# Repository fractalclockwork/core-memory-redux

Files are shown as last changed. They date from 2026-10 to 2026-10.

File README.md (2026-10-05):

# core-memory-redux

Ground-up reimplementation of a magnetic core memory array driver and its simulation-in-the-loop (SIL) digital twin.

**Agents:** start at [AGENTS.md](AGENTS.md), then [docs/AUTHORITY.md](docs/AUTHORITY.md) (SSOT map). This README is the human front door; architecture bullets below are a snapshot and defer to owner docs.

## Why this repo exists

This is a rewrite of [`fractalclockwork/core-memory`](https://github.com/fractalclockwork/core-memory), rebuilt as a model project for **simulation-in-the-loop agentic engineering**. The goal is not only a working circuit, but a repeatable process: requirements, tools, generators, fidelity-gated simulation, and documentation that stay aligned as the design evolves.

**Done** means all three deliverables:

1. The engineering process (phased SIL loop, coverage gates, agent-friendly workflow)
2. The circuit (driver for the existing 64×64 ferrite plane)
3. Documentation of the circuit, simulation ladder, and design decisions

## Status

**Docs + L0–L3 sim/SIL + L4 fabric KiCad + multi-board PCB (Phase 5+).** Design contracts live under [`docs/`](docs/). Gates `GATE-L0-PHYSICS` … `GATE-L4-FABRIC` → [coverage_matrix.md](docs/coverage_matrix.md). Generators: [`generators/`](generators/) → [`kicad/`](kicad/) (KiCad **10.0.6**), including `pcb_ccs_sense` + `pcb_axis_octal` ([board_icd.md](docs/board_icd.md)). No firmware / bench fab yet. Claims outside the coverage matrix are *normative target* / `baseline`, not as-built hardware.

**SSOT:** layered authority — one owner per fact category ([docs/AUTHORITY.md](docs/AUTHORITY.md)). Normative definition: [docs/system_design_spec.md](docs/system_design_spec.md) §1. Weave/fabric geometry SSOT: [`generators/mce_array.py`](generators/mce_array.py).

## Record

[writeup/essay.md](writeup/essay.md) is a narrative snapshot of the method, the L0–L3 runs, and the L4 fabric and boards, written as ordinary prose. It is not part of the SSOT. If it disagrees with an owner doc or the coverage matrix, those win.

## Target architecture (snapshot)

Non-authoritative summary — edit owners, not this list:

- **Plane / fold / timing:** [docs/design_specification.md](docs/design_specification.md) (`REQ-ICD-*`)
- **Drive path (DMOS):** [docs/component_selection.md](docs/component_selection.md) (`REQ-DRV-DMOS`)
- **Naming / decode call model:** [docs/naming.md](docs/naming.md) (`REQ-NAME-GATE`)
- **L4 fabric / pin budgets:** [docs/hierarchy_abi.md](docs/hierarchy_abi.md) (`REQ-HIER-OCTAL`)
- **Multi-board PCB (1 + 2×8):** [docs/board_icd.md](docs/board_icd.md) §7
- **Anti-explosion / L0–L4:** [docs/system_design_spec.md](docs/system_design_spec.md) (`REQ-SCALE-ANTIX`, `GATE-L*`)
- **Scale validation claims:** [docs/coverage_matrix.md](docs/coverage_matrix.md) only

## Open items

**Open technical decisions** (`open`): [docs/design_choices.md](docs/design_choices.md) — exact \(I_c\) / \(I_c/2\); \(V_{drive}\); inhibit polarity vs READ; Pico packaging; CCS MOSFET alternate; diagnostic LEDs.

**Deferred:** datasheet/appnote PDF tree; gated 64×64 PCB harness (1+16 layout described in [board_icd.md](docs/board_icd.md) §7); MCU firmware / real PIO bridging.

## Phased implementation / simulation / validation loop

Detail and gate IDs: [docs/system_design_spec.md](docs/system_design_spec.md). L2 assumes **DMOS** BOM.

| Phase | Focus | Gate (summary) |
|---|---|---|
| **0** | Authority, ICD, naming | [AUTHORITY.md](docs/AUTHORITY.md); owners tagged `baseline` |
| **1** | L0 — single-core physics | `GATE-L0-PHYSICS` — [coverage pass](docs/coverage_matrix.md); `uv run python scripts/run_gate.py GATE-L0-PHYSICS` |
| **2** | L1 — 2×2 oracle array | `GATE-L1-CYCLE` — [coverage pass](docs/coverage_matrix.md); `uv run python scripts/run_gate.py GATE-L1-CYCLE` |
| **3** | L2 — driver fidelity | `GATE-L2-E2E` — [coverage pass](docs/coverage_matrix.md); `uv run python scripts/run_gate.py GATE-L2-E2E` |
| **4** | L3 — ideal \(N \times N\) SIL | `GATE-L3-SIL` — [coverage pass](docs/coverage_matrix.md); `uv run python scripts/run_gate.py GATE-L3-SIL` |
| **5** | L4 — hardware fabric | `GATE-L4-FABRIC` — [coverage pass](docs/coverage_matrix.md); `uv run python scripts/run_gate.py GATE-L4-FABRIC` |
| **6** | Bench bring-up | 2×2 first; characterize \(I_c\) |

## Documentation map

| Doc | Role | Status |
|-----|---|---|
| [AGENTS.md](AGENTS.md) | Agent entry, hard bans | entry |
| [docs/AUTHORITY.md](docs/AUTHORITY.md) | SSOT map, ownership, conflict priority | `baseline` |
| [docs/system_design_spec.md](docs/system_design_spec.md) | Process, freeze table, anti-explosion, L0–L4 | `baseline` |
| [docs/design_specification.md](docs/design_specification.md) | Plane ICD, sense/inhibit, timing | `baseline` |
| [docs/design_choices.md](docs/design_choices.md) | Tradeoffs and open decisions | `baseline` / `open` |
| [docs/component_selection.md](docs/component_selection.md) | BOM (DMOS pivot) | `baseline` |
| [docs/naming.md](docs/naming.md) | Net grammar, hierarchy-as-call | `baseline` |
| [docs/hierarchy_abi.md](docs/hierarchy_abi.md) | Steer/magnetic pin budgets | `baseline` |
| [docs/board_icd.md](docs/board_icd.md) | Multi-board CCS + axis-octal connectors | `baseline` |
| [docs/coverage_matrix.md](docs/coverage_matrix.md) | Scale × surface claims | `baseline` (L0–L4 + 8×8 PCB `pass`) |
| [docs/implementation_summary.md](docs/implementation_summary.md) | Block architecture sketch | `sketch` |
| [docs/theory_of_operation.md](docs/theory_of_operation.md) | Teaching summary | `sketch` |
| [docs/references.md](docs/references.md) | Citation placeholders | `sketch` |
| [docs/dev_host_setup.md](docs/dev_host_setup.md) | Ubuntu apt + `uv` host install | `sketch` |

## Dev-host tooling

Ubuntu apt packages and the `uv` Python environment: [docs/dev_host_setup.md](docs/dev_host_setup.md). Host stack: Python (`uv`), ngspice / PySpice, and KiCad 10.0.6 (`kicad-cli`) for L4 fabric ERC and multi-board ERC/DRC. RP2040 SDK is deferred (not current host setup).

## Upstream and non-goals

- **Upstream:** [fractalclockwork/core-memory](https://github.com/fractalclockwork/core-memory) — history only, not SSOT for this tree.
- **Not carrying over:** discrete MOSFET + TC4427 primary architecture; monolithic 256-end L4 ABI; as-built claims until regenerated from AST / phased loop.

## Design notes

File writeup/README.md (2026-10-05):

# Record

This folder is a human telling of work already in the repository: the method, the simulation-in-the-loop ladder, the figures from the L0–L3 runs, and the L4 fabric and multi-board boards as they stand. It is a snapshot. The design contracts in [`docs/`](../docs/) and the scale claims in [`docs/coverage_matrix.md`](../docs/coverage_matrix.md) are the source. If this prose and an owner disagree, the owner wins. Nothing here is an input to later design.

Regenerate the figures and the measured numbers with:

```bash
uv run --group writeup python writeup/scripts/render_figures.py
```

The essay is [essay.md](essay.md).

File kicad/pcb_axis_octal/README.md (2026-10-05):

# pcb_axis_octal (GENERATED)

GENERATED by generators/ — do not hand-edit; uv run python -m generators.cli --board axis

- Schematic: `pcb_axis_octal.kicad_sch`
- PCB: `pcb_axis_octal.kicad_pcb`
- Identical PCB for X and Y; strap JP_AXIS / JP_G
- ICD: `docs/board_icd.md`

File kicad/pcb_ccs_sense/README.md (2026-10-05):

# pcb_ccs_sense (GENERATED)

GENERATED by generators/ — do not hand-edit; uv run python -m generators.cli --board ccs

- Schematic: `pcb_ccs_sense.kicad_sch`
- PCB: `pcb_ccs_sense.kicad_pcb`
- ICD: `docs/board_icd.md`

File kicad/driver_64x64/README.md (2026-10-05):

# driver_64x64 (GENERATED)

GENERATED by generators/ — do not hand-edit; uv run python -m generators.cli --n 64

- Root: `driver.kicad_sch`
- Manifest: `fabric_manifest.json`
- Gate: **GATE-L4-FABRIC** / **REQ-HIER-OCTAL**

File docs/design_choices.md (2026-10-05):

# Design Choices

**Status:** `baseline` for recorded tradeoffs; open rows below are `open`  
**Owns:** tradeoffs + open decisions  
**Does not own:** frozen ICD — see [AUTHORITY.md](AUTHORITY.md)

Part-level picks: [component_selection.md](component_selection.md). Net grammar / call model: [naming.md](naming.md). Pin budgets: [hierarchy_abi.md](hierarchy_abi.md). Normative freeze table: [system_design_spec.md](system_design_spec.md) §1.

## Three-wire cores: no separate inhibit winding

Each core carries **X**, **Y**, and **sense** only (classic 3-wire). There is no fourth inhibit wire through the array. WRITE-0 inhibit reuses the sense path at high current; READ uses the same path as a millivolt differential. That time-multiplex forces Sense-block isolation (1 kΩ), clamps, and soft center-tap bias before Inhibit can source `YA65` and sink `YB66` into the CCS.

## Series differential sense (shared READ / inhibit loops)

The plane has two independent sense/inhibit loops (`YA65`↔`YA66` and `YB65`↔`YB66`), 2,048 cores each. The driver joins them with an external center-tap jumper **`YA66`═`YB65`** and uses the outer ends (`YA65`/`YB66`) as a differential pair. That rejects common-mode drive noise that would swamp a single-ended pickup, and it keeps a single TLV3501 and a single inhibit driver. A dedicated sense-only winding is not available on this hardware, so the driver must protect and bias this shared path for both READ (small-signal) and INHIBIT (high current).

Each loop’s DCR and inductance are half of a continuous 4,096-core weave. Wiring the loops in series presents that full-array L and DCR to the driver, so \(V_{drive}\) and the CCS current stay at \(I_c/2\).

If the series-loop noise floor is too high on the bench, the deferred alternative is to drive and sense the loops in parallel: `YA65` and `YB65` both fed from the inhibit P-FET, `YA66` and `YB66` both returned to `CCS_INH` (that sink then takes \(I_c\), and \(V_{drive}\) can be lower), plus a second TLV3501 whose output is OR’d with the first. That is not the 2×2 sim fixture or the initial build target.

## The TBD62083/TBD62783 matrix array

Driving 64 X and 64 Y lines as discrete half-bridges would explode component counts and hierarchical sheet counts. The design uses an 8×8 crossbar with Toshiba DMOS sink/source arrays (TBD62083/TBD62783). These replace dozens of discrete MOSFETs and gate drivers, giving SN75325-like density without BJT turn-off drag that would blur the inductive read spike. Twelve address bits feed four decode banks (X/Y × FWD/REV); each bank’s 8+8 outputs trigger the DMOS arrays directly.

## Steering diodes on the driver board

The 8×8 addressing geometry creates passive matrix sneak paths across unselected lines. Discrete Schottky steering diodes (SS14) remain mandatory on the driver at matrix outputs. The core PCB contains no diodes. At L4, diodes live in octal steer tiles rather than one monolithic 256-end sheet ([hierarchy_abi.md](hierarchy_abi.md)).

## Why not simulate all 256 ends at full fidelity

The plane’s 256 drive ends are a **physical** fact. Making them the default unit of SPICE fidelity or KiCad hierarchical pins recreates the failure mode this rewrite avoids: root-sheet pin explosion, duplicated stub nets, and nonlinear transients that cannot finish at n=64.

Instead:

* Control and L2 ABI stay at **bank level** (8 HS + 8 LS) with DMOS 8-channel atoms ([naming.md](naming.md)).
* L0 Chan physics stays ≤16 cores; L1/L2 prove the cycle at **2×2**; L3 scales with behavioral `ideal_core` ([system_design_spec.md](system_design_spec.md) §4–5).
* L4 compresses plane ends with octal tiles and KiCad buses ([hierarchy_abi.md](hierarchy_abi.md)).
* Scale claims require a [coverage_matrix.md](coverage_matrix.md) row.

## Prototype 2×2 before scaling lines

Bring-up and L1/L2 prove a full READ → STROBE → INHIBIT → WRITE cycle on the **2×2** before trusting n×n SIL. Drive hierarchy targets 8-channel DMOS arrays; decode is one hierarchical page per axis (74AHC138 HS + 74AHC238 LS). Fabric and multi-board KiCad are generated from AST/emitters ([AUTHORITY.md](AUTHORITY.md) Layer D); scale gates: [system_design_spec.md](system_design_spec.md), [coverage_matrix.md](coverage_matrix.md).

## Soft mid-bias and input clamps on sense

During inhibit, the outer ends see large excursions. BAT54S clamps dump spikes into the rails; a soft resistive bias from the center tap (`YA66`/`YB65`) to AGND keeps the comparator inputs from floating between cycles. Isolation resistors (e.g. 1 kΩ in Sense) limit clamp current into the amp (~8 mA into clamps at 12 V). This favors a modern fast comparator (TLV3501) over older ±supply parts that assumed different front-ends.

A 1:1 pulse-transformer sense front-end was considered and **deferred**: on this 3-wire plane the same fold ends carry series inhibit, so a low-DCR primary across those pins would shunt inhibit current around the cores. AC-coupling the primary would still slam inhibit edges onto the secondary and force clamps/blanking, erasing the BOM win. DC-coupled Sense stays.

## Manual TL431 + trimpot CCS

Bench bring-up needs a knob for \(I_c/2\) while probing cores of uncertain coercivity (400–800 mA full-select estimate). A TL431 reference and multi-turn 3296W divider set the OPA192 target without firmware or a DAC. A later digital setpoint (DAC or PWM + filter) can replace the trimpot once the operating current is known; the MOSFET + sense-resistor power stage stays.

## Schematic defaults + bench-tunable bring-up

Bench characterization needs a **highly functional** driver (complete schematic + PCB), not a one-shot fixed setpoint. Therefore:

1. **Do not freeze** exact \(I_c\), \(V_{drive}\), or inhibit-vs-READ polarity as ICD until measured ([system_design_spec.md](system_design_spec.md) §1 non-normative column stays).
2. **Do freeze schematic intent:** the board must ship with informed *defaults* and explicit *tune points* so bring-up can sweep the ICD band without a respin for every guess.
3. **L4 / PCB acceptance:** a “complete” fabric is one that exposes the knobs below; claiming bench-ready without them is a gap.

### Informed defaults (start of bring-up, not ICD)

| Parameter | Schematic / sim default | Rationale |
|---|---|---|
| \(I_c\) / \(I_c/2\) | 600 mA / 300 mA | Mid of ICD 400–800 mA full-select band; matches L0–L3 sim assumption |
| \(V_{drive}\) | Design for ~12 V class rail with margin (exact value open) | Headroom for DMOS + SS14 + inductive \(L\,di/dt\) on series fold; finalize on bench |
| Inhibit vs READ | Default: source `YA65`, sink `YB66` into `CCS_INH` at \(-I_c/2\) during WRITE-0 | Matches [design_specification.md](design_specification.md) **REQ-ICD-FOLD** / **REQ-ICD-TIMING** and L1–L3 plants |

### Mandatory tune / select points on the board

| Knob | Mechanism (normative intent) | Band / options |
|---|---|---|
| Half-select current | Per-CCS multi-turn trimpot (TL431 divider) on `CCS_X`, `CCS_Y`, `CCS_INH` | Cover ~200–400 mA \(I_c/2\) without BOM change |
| \(V_{drive}\) | Adjustable bench supply into a dedicated rail (or on-board regulator with set resistor / trimpot) | Sweep until full-select and inhibit stay in regulation under pulse load |
| Inhibit / sense polarity | Board-level select (jumper, 0 Ω option, or MOSFET H-bridge steer) so `YA65`/`YB66` source–sink roles can reverse if the plane’s weave disagrees | Two discrete orientations; default as above |
| Timing aperture | PIO (or equivalent) parameters for READ width and SENSE STROBE (~150–300 ns) | Firmware-tunable once packaging is chosen |

Sim and SIL keep using the defaults above as **sim assumptions** until a coverage **Bench** cell records measured values. After characterization, promote the settled numbers into the freeze table / ICD only via the owning docs—not by hard-coding unmeasured setpoints into L4 as if they were frozen.

## AHC logic and DMOS compatibility

The timing controller is 3.3 V (RP2040). 74AHC138/238 accept 3.3 V inputs with short propagation delay. The DMOS arrays (TBD62083/783) accept these logic levels directly—no dedicated level shifters. Low-side decode uses 74AHC238 (active-high) to match sinks; high-side uses 74AHC138 (active-low) to match sources.

FWD vs REV steering uses duplicated decoder banks gated by `FWD_EN_n` / `REV_EN_n`. That removes a mux layer and keeps fail-safe behavior native.

## RP2040 PIO for timing

READ → strobe → inhibit → WRITE needs fixed delays on the order of hundreds of nanoseconds. Main-CPU GPIO toggling under an OS or interrupt load introduces jitter that corrupts sense windows. PIO state machines give cycle-accurate multi-pin sequences while application code runs elsewhere. Another MCU with equivalent programmable I/O could substitute; the requirement is hardware sequencing, not the Pico brand.

## Multi-board packaging (one host + 2×8 axis)

**One** `ccs_sense` host distributes address / `VDRIVE` / enables and owns CCS, sense/inhibit/fold, and write-back (`DOUT`). **Axis-octal** boards are identical copies: bring-up uses 1×X + 1×Y at `g=0` (three boards → 8×8); full 64×64 repeats to **2×8 = 16** axis boards with unique `JP_G` straps. Full roster / harness: [board_icd.md](board_icd.md) §7. Electrical ABI unchanged ([hierarchy_abi.md](hierarchy_abi.md) **REQ-HIER-OCTAL**).

## Decisions still open

| Topic | Notes |
|---|---|
| Exact \(I_c\) / \(I_c/2\) setpoint | **Default 600 / 300 mA** for schematic + sim; **tune** on CCS trimpots across 200–400 mA half-select; freeze only after bench |
| \(V_{drive}\) rail voltage | **Default ~12 V class** with adjustable supply/regulator; must clear DMOS + diode + inductive headroom; freeze after bench |
| Inhibit polarity vs READ | **Default** source `YA65` / sink `YB66`; **board select** must allow reverse if weave polarity disagrees |
| On-board vs off-board RP2040 | Pico header vs soldered MCU vs external timing pod |
| Final CCS throttle MOSFET | IRLZ44N in CCS; AOD4184 (or similar) remains a thermal/package alternate |
| Diagnostic LED set | Planned on decoder outputs and DOUT; not yet a frozen schematic requirement |

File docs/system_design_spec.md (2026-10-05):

# Core Memory Driver & Digital Twin: System Design Specification

**Status:** `baseline` (Phase 0 contract)  
**Owns:** process, normative freeze table, L0–L4 gates, anti-explosion rules  
**Does not own:** plane ICD detail, timing prose, BOM tables, pin budgets — see [AUTHORITY.md](AUTHORITY.md)

Plane/timing ICD: [design_specification.md](design_specification.md). Net grammar: [naming.md](naming.md). Fabric pin budgets: [hierarchy_abi.md](hierarchy_abi.md).

## 1. Normative target architecture

**Normative target architecture** is the set of contracts that every generated schematic, SPICE plant, SIL plant, and future bench fixture **must** conform to before a fidelity layer may advance. It is the *intended* architecture for this rewrite, not an as-built report of any prior tree.

Anything that contradicts the left column below is a **doc bug** until formally revised. Open items stay listed; they are not silently frozen. Ownership of each row’s detail is in [AUTHORITY.md](AUTHORITY.md).

| Normative (frozen by Phase 0 / L2 ABI) | Non-normative (open until bench) |
|---|---|
| Plane ICD: 64×64, 3-wire, XA/XB/YA/YB, physical 1–64 vs logical 0–63, Y65/66 sense | Exact \(I_c\) / \(I_c/2\) |
| Series fold `YA66`═`YB65`, outer ends `YA65`/`YB66`, soft mid-tap | Exact \(V_{drive}\) |
| Drive topology: AHC decode → TBD62783/TBD62083 → SS14 → CCS×3 | Inhibit polarity vs READ |
| Timing contract: READ → STROBE → INHIBIT → WRITE; RP2040 PIO requirement | Pico packaging, LED set, CCS MOSFET alternate |
| Naming layers + hierarchical ABI (bank-level control; sense outside Drive/Decode) | Parallel-loop sense alternative (deferred) |
| Fidelity ladder gates L0–L4 and coverage-before-scale rule | Generator/board paths: see [AUTHORITY.md](AUTHORITY.md) Layer D |

## 2. Architectural strategy & core principles

The architecture abandons monolithic, transient-heavy full-matrix SPICE in favor of a layered digital twin. Three artifact classes:

1. Physical physics model (single-core / small-N calibration)
2. Idealized array plant (logical coincidence at scale)
3. Hardware schematic fabric (generated CAD)

**Governing principles:**

* **Fidelity is a dial.** Simulation fidelity scales from nonlinear ODEs (single core) to \(O(1)\) behavioral logic (full matrix).
* **Weave AST → KiCad.** [`generators/mce_array.py`](../generators/mce_array.py) is the fabric geometry SSOT and emits hierarchical KiCad ([AUTHORITY.md](AUTHORITY.md) Layer D). SPICE decks and L3 SIL plants remain separate harnesses (not cross-emitted from the weave AST). Scale claims stay coverage-gated.
* **Manufacturing-aligned boundaries.** Hierarchical blocks match plane pinouts and scaling constraints; they do not expose 256 drive ends through decode/drive sheets.
* **Performance as a gate.** No simulation layer advances without a runtime budget.

## 3. ICD pointer (normative detail elsewhere)

All generated schematics and simulation plants must conform to the frozen plane interface, sense/inhibit fold, drive topology, and timing in **[design_specification.md](design_specification.md)**. Net grammar and decode/DMOS call model: **[naming.md](naming.md)**.

**Essentials (anti-explosion context only — do not edit ICD here):**

* The plane has **256** physical drive ends; that surface is real hardware and is **not** the default unit of sim fidelity or root-sheet pin budget.
* Control stays bank-level (8 HS + 8 LS); sense/fold nets stay outside Drive/Decode.
* Gate-net audit regex lives in [naming.md](naming.md) §2 (do not fork a second copy here).

## 4. Anti-explosion rules (normative)

**REQ-SCALE-ANTIX** — The plane’s 256 drive ends must never be the default unit of simulation fidelity, hierarchical pin budget, or root-sheet wiring.

1. **Control stays bank-level.** Decode exposes `N_HS{0..7}_n` / `N_LS{0..7}_en` (8+8), not 64 line pins per axis. Line select is \(line = 8 \cdot HS + LS\). Sense/fold nets never enter Drive/Decode pins.
2. **DMOS is the drive atom.** Hierarchical drive fabric is 8-channel array blocks (TBD62783 / TBD62083), not 256 discrete half-bridges and not per-line TC4427 blocks as the primary ABI. BOM detail: [component_selection.md](component_selection.md); ID **REQ-DRV-DMOS**.
3. **L0 never scales.** Chan / detailed physics: ≤16 instances; never the n=64 proof.
4. **L1/L2 prove the cycle at n=2.** Full WRITE/READ/INHIBIT and driver-BOM e2e stay on the 2×2 oracle; L2 freezes decode/drive ABI there.
5. **L3 is the only full-matrix sim path.** Behavioral `ideal_core` + line \(R/L/C\) + sparse/diagonal patterns; runtime in minutes. No 4,096 nonlinear cores.
6. **L4 fabric tiles the 256 ends.** Prefer octal steer tiles and root buses `XA[0..63]`…; forbid monolithic 320-pin steer + duplicated ~512 root stubs as the target ABI. Fold stays local on the magnetic sheet. Details: [hierarchy_abi.md](hierarchy_abi.md).
7. **Coverage before scale.** No n×n schematic/SIL claim without a [coverage_matrix.md](coverage_matrix.md) row.

```mermaid
flowchart TB
  subgraph control [Control plane O8]
    Addr[12bit ADDR]
    Dec[decode_block x4]
    Dmos[DMOS arrays 8ch]
    Addr --> Dec --> Dmos
  end
  subgraph fabric [Fabric boundary]
    Octal[steer octal tiles]
    Buses[KiCad buses XA XB YA YB]
    Fold[SENSE_FOLD local]
    Dmos --> Octal --> Buses
    Fold -.-> Buses
  end
  subgraph sim [Sim scale dial]
    L0[L0 Chan max 16]
    L1[L1 2x2 ideal switches]
    L2[L2 driver BOM at n2]
    L3[L3 ideal_core NxN]
    L0 --> L1 --> L2
    L1 --> L3
  end
```

## 5. The fidelity ladder

Aligned with project phases 1–5 in the root README (Phase 0 = doc/ICD freeze; Phase 6 = bench).

### Layer 0: Detailed physics (single core)

**GATE-L0-PHYSICS**

* **Implementation:** SPICE Chan model (`K` statement) parameterized for 50-mil cores (\(L_m \approx 0.00314\) m, \(A_c \approx 0.097\) µm², \(H_c \approx 150\) A/m). Parallel damping for ~1 µs peaking.
* **Gates:** Stable half-select hold, read-1 amplitude discrimination, restore polarity.
* **Constraint:** Calibration only. Never scale beyond 16 cores without a runtime budget check.

### Layer 1: Oracle array (2×2 matrix)

**GATE-L1-CYCLE**

* **Implementation:** SPICE transient deck with 4 `coremem` (or equivalent) instances, 3× ideal CCS sinks, and the `YA66`═`YB65` fold ([design_specification.md](design_specification.md) **REQ-ICD-FOLD**).
* **Gates:** Full WRITE/READ/INHIBIT cycle. Single-CCS failure deck remains a persistent regression.

### Layer 2: Driver fidelity & ABI lock

**GATE-L2-E2E**

Still at **n=2**. Substitutes ideal L1 switches with the finalized silicon BOM:

**74AHC138, 74AHC238, TBD62783, TBD62083, SS14, TLV3501** (plus Sense latch / CCS parts per [component_selection.md](component_selection.md) **REQ-DRV-DMOS**).

* **Gates:** Address-pin end-to-end cycle timing, strobe window (~150–300 ns), fail-safe pull-ups/downs, FWD/REV mutex.
* **Output:** Freezes schematic ABI (`decode_block` and DMOS drive-array block pinouts). Discrete TC4427A + FDS8958A is **not** the L2 BOM.

### Layer 3: Idealized \(N \times N\) & SIL

**GATE-L3-SIL**

* **Implementation:** Ideal behavioral core (threshold-law \(I_c\) flip, fixed sense pulse) + line impedance (\(R\), \(L\), line-to-ground \(C\)).
* **SIL:** Plant driven by synthetic PIO/decode stimuli (e.g. PySpice bridging to MCU firmware).
* **Gates:** Full diagonal and random sparse patterns; continuous runs finish in minutes.

### Layer 4: Hardware fabric generation

**GATE-L4-FABRIC**

* **Implementation:** Weave AST ([`generators/mce_array.py`](../generators/mce_array.py)) + emitter ([`generators/emit_kicad.py`](../generators/emit_kicad.py)) produce octal steer tiles and bus-rooted fabric (`bringup_2x2`, `driver_64x64`). Multi-board PCBs: [`generators/emit_boards.py`](../generators/emit_boards.py) → [board_icd.md](board_icd.md). Pin budgets: [hierarchy_abi.md](hierarchy_abi.md).
* **Gates:** Clean ERC. Zero hand-edits on generated sheets; topological fixes flow from the AST/emitter scripts.

## 6. Generator pipeline & documentation

Fabric geometry SSOT is the weave AST (`generators/mce_array.py` → `emit_kicad.py`). Board packaging SSOT is `generators/board_abi.py` + `emit_boards.py` ([board_icd.md](board_icd.md)). Documentation is an active test surface: scale claims require a [coverage_matrix.md](coverage_matrix.md) row showing which surfaces (Schematic, PCB, SPICE, SIL, Bench) are validated at a given \(N \times N\). Hardware commitments must not outpace simulation capability.

## 7. Phase map (process)

| Phase | Focus | Doc / ladder home |
|---|---|---|
| **0** | Resolve doc conflicts; freeze ICD + naming | [AUTHORITY.md](AUTHORITY.md); this doc §§1–4; [naming.md](naming.md); [design_specification.md](design_specification.md) |
| **1** | L0 single-core physics | §5 **GATE-L0-PHYSICS** |
| **2** | L1 2×2 oracle + CCS failure regression | §5 **GATE-L1-CYCLE** |
| **3** | L2 driver fidelity (DMOS BOM) + ABI freeze | §5 **GATE-L2-E2E** |
| **4** | L3 ideal \(N \times N\) SIL | §5 **GATE-L3-SIL** |
| **5** | L4 AST → KiCad (tiled fabric) | §5 **GATE-L4-FABRIC**; [hierarchy_abi.md](hierarchy_abi.md) |
| **6** | Bench bring-up (2×2 first), then scale | Open decisions in [design_choices.md](design_choices.md) |

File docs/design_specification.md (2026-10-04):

# Magnetic Core Memory Drive and Sense Circuit: Design Specification

**Status:** `baseline` (Phase 0 contract)  
**Owns:** plane physical ICD, sense/inhibit electrical contract, timing sequence  
**Does not own:** process phases, L0–L4 gates, BOM tables — see [AUTHORITY.md](AUTHORITY.md)

Normative plane interface, drive architecture, and timing contract for this rewrite. Part of the **normative target architecture** in [system_design_spec.md](system_design_spec.md) §1. Narrative context: [theory_of_operation.md](theory_of_operation.md). Citation keys `[cite: 1]` / `[cite: 2]`: [references.md](references.md).

## 1. Physical Parameters & Interface Specification

**REQ-ICD-PLANE**

* **PCB Dimensions:** The magnetic core plane is constructed on a 9-inch square PCB featuring four edge connector interfaces labeled XA, XB, YA, and YB [[cite: 1](references.md#core-plane-physical-evidence)].
* **Connector Type:** Dual-readout staggered edge connector.
* **Contact Dimensions:** Pins are 0.125" wide with a 0.1875" (3/16") center-to-center pitch on each face.
* **Staggered Layout:** Odd-numbered pins are located on the top face [[cite: 1](references.md#core-plane-physical-evidence)], and even-numbered pins are located on the bottom face [[cite: 2](references.md#core-plane-physical-evidence)]. Pin 1 begins 1.3125" (1-5/16") from the right edge, offsetting the top and bottom contacts by exactly 0.0625" to maximize contact area while preventing wiper shorts during insertion.
* **Axis Connectors:**
    * **X-Axis (XA, XB):** 64 pins total. Requires a 32-position, dual-readout staggered receptacle.
    * **Y-Axis (YA, YB):** 66 pins total. Requires a 33-position, dual-readout staggered receptacle.
* **Matrix Capacity:** 64×64 bidirectional drive lines yield exactly 4,096 cores (512 bytes).
* **Pin numbering vs address:** Physical edge contacts are labeled **1–64** (drive) plus Y **65/66** (sense). Schematic and firmware address drive lines **0–63**. Mapping: physical pin \(p\) ↔ logical index \(p-1\). Pins 65/66 are **not** drive lines and are **not** part of the Drive/Decode hierarchical pin chain — see §1.1 and §2.
* **Dual sense loops:** Pins 65/66 on YA and YB are two independent loops, 2,048 cores each (`YA65`↔`YA66` and `YB65`↔`YB66`). The plane does not join them. Each loop’s DCR and inductance are half of a single weave through all 4,096 cores. The driver ties `YA66`═`YB65` (external center tap) so the series path is `YA65` → Loop A → jumper → Loop B → `YB66`. Series connection restores the full-array L and DCR. [[cite: 1](references.md#core-plane-physical-evidence),[cite: 2](references.md#core-plane-physical-evidence)]

### 1.1 Three naming layers (keep separate)

Normative net grammar, block ABI, buses, and scale path: **[naming.md](naming.md)**. Fabric pin budgets: **[hierarchy_abi.md](hierarchy_abi.md)**. Mixing physical (1–64 / Y 65–66), syntax (`XA0`…, block `N`/`n`), and semantic (drive vs sense/fold) layers is a recurring source of schematic and doc bugs. Drive/Decode hierarchical pins only cover the matrix control plane (bank-level)—do not extend that chain to 65/66, and do not put all 256 plane ends through decode sheets.

## 2. Sense and Inhibit Architecture (Pins 65 & 66)

**REQ-ICD-FOLD**

Each core is a **three-wire** element (X, Y, sense). There is **no separate inhibit winding**; inhibit is series current on the folded sense wire, time-multiplexed with READ.

* **Two loops + external fold:** Loop A `YA65`↔`YA66`; Loop B `YB65`↔`YB66`. Driver jumper **`YA66`═`YB65`**. Outer ends: `YA65` / `YB66`. The 2×2 magnetic fixture is the schematic stand-in (one diagonal per loop).
* **Common-Mode Noise Rejection (Read Phase):** A high-speed differential comparator (TLV3501; see [component_selection.md](component_selection.md)) across `YA65` / `YB66` isolates the millivolt flip spike. Classic techniques: Linear AN13 (PDF deferred to a later datasheet/appnote pass).
* **Center-Tap Bias:** Soft-bias the center tap `YA66`/`YB65` (10 kΩ → AGND), not a hard AGND short, so inhibit current traverses both loops into the CCS.
* **Series Inhibit Drive (Write Phase):** Source \(V_{drive}\) into `YA65` and sink `YB66` to `CCS_INH` at \(-I_c/2\), so current flows Loop A, crosses `YA66`═`YB65`, and returns through Loop B — all cores in series. A parallel-drive alternative (both loops at once, two comparators) is deferred; see [design_choices.md](design_choices.md).

## 3. Drive Architecture (64×64 Matrix)

**REQ-ICD-DRIVE** — electrical/matrix contract. Part MPNs: [component_selection.md](component_selection.md) **REQ-DRV-DMOS**. Anti-explosion: [system_design_spec.md](system_design_spec.md) **REQ-SCALE-ANTIX**.

* **Matrix Structure:** Group the 64 lines per axis into 8 rows and 8 columns. Implement 8 High-Side source switches and 8 Low-Side sink switches per axis, per direction (Forward for READ, Reverse for WRITE). Control and simulation stay at this **8×8 bank** geometry—not as 256 independent full-fidelity switch models.
* **Address Decoding:** A 12-bit address word maps to this geometry. 6 bits decode X (3 HS + 3 LS), 6 bits decode Y. Decoders: 74AHC138 HS / 74AHC238 LS; see [component_selection.md](component_selection.md).
* **DMOS Array Switching:** High-current switching uses monolithic 8-channel DMOS arrays (TBD62783 sources / TBD62083 sinks). These take AHC decoder outputs directly. Discrete per-line MOSFET + TC4427 drive is not the normative architecture.
* **Steering Diodes:** Because there are no discrete diodes on the memory plane itself [[cite: 1](references.md#core-plane-physical-evidence),[cite: 2](references.md#core-plane-physical-evidence)], SS14 Schottkys sit on the driver at matrix outputs (octal steer tiles at L4; see [hierarchy_abi.md](hierarchy_abi.md)).

## 4. Current Recommendations (\(I_c\))

* **Coercive Current (\(I_c\)):** Given the 0.125-inch core diameter, expect a full-select current between 400 mA and 800 mA. Exact setpoint is non-normative until bench characterization ([design_choices.md](design_choices.md)).
* **Drive Regulation:** Half-select (\(I_c/2\), ~200–400 mA) must be regulated on each axis. Three copies of the same adjustable CCS: `CCS_X`, `CCS_Y`, `CCS_INH`. One shared sink would split the coincident pulse so the addressed core never sees full-select. Power op-amp + N-channel MOSFET + sense resistor holds each path flat into the inductive load.

## 5. Timing & Sequencing

**REQ-ICD-TIMING**

Core memory operations require sub-microsecond, deterministic pulse sequencing. A READ destroys the data, so every access is a READ / RESTORE cycle.

1. **READ Phase:** Drive \(-I_c/2\) into the target X and Y lines.
2. **SENSE STROBE:** Wait ~150–300 ns for capacitive ringing to settle, then clock the D-flip-flop on the differential comparator across `YA65` / `YB66`.
3. **INHIBIT Phase:** If writing/restoring a '0', drive \(-I_c/2\) from `YA65` through the `YA66`═`YB65` center tap and out `YB66`.
4. **WRITE Phase:** Drive \(+I_c/2\) into the target X and Y lines.

Software bit-banging introduces cycle jitter that corrupts sense windows. Hardware sequencing (RP2040 PIO or equivalent programmable I/O) is the normative timing requirement; the Pico brand is replaceable.

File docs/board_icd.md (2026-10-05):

# Board ICD — CCS/sense host + axis-octal modules

**Status:** `baseline` (mechanical / packaging contract for multi-board bring-up and 64×64 scale-out)  
**Owns:** board split, connector pinouts, 8×8 bring-up wiring, 2×8 axis replication for 64×64  
**Does not own:** plane physical ICD, BOM MPNs, gate criteria — see [AUTHORITY.md](AUTHORITY.md)

Electrical ABI stays [naming.md](naming.md) / [hierarchy_abi.md](hierarchy_abi.md) **REQ-HIER-OCTAL**. Bus net grammar bridge: [naming.md](naming.md) §4.1. Tune knobs: [design_choices.md](design_choices.md). BOM MPNs + multi-board quantities: [component_selection.md](component_selection.md) §6 / [`bom_multiboard.csv`](bom_multiboard.csv). Generated KiCad: [`kicad/pcb_ccs_sense/`](../kicad/pcb_ccs_sense/), [`kicad/pcb_axis_octal/`](../kicad/pcb_axis_octal/) from [`generators/`](../generators/).

## 1. Architecture

Two PCB designs only:

| Design | Role |
|---|---|
| **`ccs_sense` (one host)** | Distributes **address**, **`VDRIVE`**, logic power, and bank enables on the control bus. Owns all **CCS**, **sense / inhibit / fold**, and **write-back** path (comparator → latch → `DOUT`). Pico (or equivalent) timing sits here. |
| **`axis_octal` (repeated)** | Identical decode + DMOS + SS14 board for **8 lines** (one HS group). Same copper for X or Y; straps set axis and unique group address `g=0..7`. |

### Quantities

| | Bring-up (prove) | Full array (64×64) |
|--|---:|---:|
| `ccs_sense` | **1** | **1** (unchanged) |
| `axis_octal` | **2** = 1×X + 1×Y at `g=0` | **16** = **2×8** (8×X + 8×Y, `g=0..7`) |
| Cores exercised | 8×8 | 64×64 |

Scale-out is **replication with unique address straps**, not a new axis PCB. The host still fans out ADDR / `VDRIVE` / enables; each axis board owns only its eight plane lines.

```text
                    ┌─────────────────────────────────────┐
                    │  ccs_sense (×1)                     │
  Pico / PIO ──────►│  ADDR, EN, VDRIVE, +3V3 distribution│
                    │  CCS_X / CCS_Y / CCS_INH            │
                    │  sense + fold + write-back (DOUT)    │
                    └──────────────┬──────────────────────┘
                                   │ J_BUS (star @ 64×64; daisy OK @ 8×8)
          ┌────────────────────────┼────────────────────────┐
          ▼                        ▼                        ▼
   axis_octal X g=0 … g=7    axis_octal Y g=0 … g=7    (16 boards = 2×8)
          │                        │
          └──────────► ferrite plane XA/XB / YA/YB + YA65/YB66
```

Bring-up uses only the `g=0` pair (three boards total). Full array is **1 + 2×8 = 17** boards — roster and harness in §7.

## 2. Stackup / mechanics

- **Layers:** **4-layer preferred** for the full-array host and all axis boards (Sig / GND / PWR / Sig). 2-layer remains acceptable only as an early **CCS prototype** exception if the CCS MOSFET has copper pour + heatsink.
- **Axis board size target:** ≤ 100×80 mm (octal connectors + DMOS SOIC-18s).
- **CCS board size target:** ≤ 120×80 mm (three linear CCS + sense + Pico header + bus host).
- **Connectors:** 2.54 mm pin headers unless noted; high-current CCS/`VDRIVE` use ≥ 3.5 mm screw terminal or 0.1" doubled pins paralleled.

## 3. Control / power bus (`J_BUS`)

Hosted **only** on `ccs_sense`; every `axis_octal` is a bus receptacle. The host is the single source of address and `VDRIVE` for the array.

| Pin | Net | Dir (from CCS) | Notes |
|----:|-----|---|---|
| 1 | `+3V3` | out | Logic |
| 2 | `AGND` | out | |
| 3 | `VDRIVE` | out | ~12 V class adjustable; one rail to all axis boards |
| 4 | `AGND_PWR` | out | Power return |
| 5 | `ADDR_NL0` | out | LS address bit 0 |
| 6 | `ADDR_NL1` | out | |
| 7 | `ADDR_NL2` | out | |
| 8 | `ADDR_NH0` | out | HS / group select bit 0 |
| 9 | `ADDR_NH1` | out | |
| 10 | `ADDR_NH2` | out | |
| 11 | `FWD_EN_n` | out | Active-low; pull-up on axis |
| 12 | `REV_EN_n` | out | Active-low; pull-up on axis |
| 13 | `DEC_EN` | out | Active-high; pull-down on axis |
| 14 | `CCS_RET_AXIS` | in | Axis CCS return (wired to `CCS_X` or `CCS_Y` per harness) |
| 15 | `AXIS_ID0` | out | Optional strap echo / ID |
| 16 | `AXIS_ID1` | out | |

`CCS_RET_AXIS` is **axis-specific in harness wiring**: host provides `J_CCS_X` and `J_CCS_Y` (and `J_CCS_INH` stays on the sense/inhibit path). X boards’ pin 14 → `CCS_X`; Y boards’ pin 14 → `CCS_Y`.

## 4. `ccs_sense` board (host)

### 4.1 Functions

- **Distribution:** address bits, `FWD_EN_n` / `REV_EN_n` / `DEC_EN`, `+3V3`, `VDRIVE` onto `J_BUS`.
- **CCS×3:** `CCS_X`, `CCS_Y`, `CCS_INH` — TL431 + 3296W + OPA192 + IRLZ44N + 1 Ω sense.
- **Sense / inhibit / fold:** 1 kΩ iso, BAT54S, TLV3501; **INH_POL_SEL**; `YA66`═`YB65`═`SENSE_FOLD` with 10 kΩ → AGND.
- **Write-back:** sense comparator → 74AHC74 latch → `DOUT` (and `SENSE_STROBE` from Pico). This path exists only on the host — not on axis boards.
- Pico-compatible header (`J_PICO`): PIO timing + GPIO that drive the bus.
- Plane sense connector `J_PLANE_SENSE`: `YA65`, `YB66`, `YA66`, `YB65` (+ AGND via harness/`J_BUS`).

### 4.2 Tune points (design_choices)

| Ref | Function |
|-----|---|
| `RTRIM_X` / `RTRIM_Y` / `RTRIM_INH` | Ic/2 ~200–400 mA |
| `VDRIVE` input | Adjustable bench supply (distributed to all axis boards) |
| `JP_INH_POL` | Inhibit polarity select |
| PIO | READ / STROBE / INHIBIT / WRITE aperture |

### 4.3 Sense nets

`YA65`, `YB65`, `YA66`, `YB66`, `SENSE_FOLD` live **only** on this board (+ plane cable). They never appear on `axis_octal`.

### 4.4 PCB connector copper (fab layout)

Schematic keeps the full Pico + sense pin lists. The generated PCB uses **one pad per net** so DRC stays clean without an autorouter:

| Footprint | PCB nets |
|---|---|
| `J_BUS` | Full bus (§3), including `+3V3` / `AGND` / `VDRIVE` / ADDR / enables |
| `J_PLANE_SENSE` | `YA65`, `YB66`, `YA66`, `YB65` (AGND return via bus/`AGND` harness) |
| `J_PICO` | `SENSE_STROBE`, `DOUT`, `PIO_STROBE` (ADDR/EN/power fan-out is on `J_BUS`) |
| `J_CCS_X/Y/INH` | Single pin each (`CCS_X`, `CCS_Y`, `CCS_INH`) |

Harness or short jumpers complete Pico GPIO→bus and AGND returns as needed on the bench.

## 5. `axis_octal` board (identical X/Y, unique `g`)

### 5.1 Identity straps (unique address)

| Strap | Meaning |
|---|---|
| `JP_AXIS` | `X` or `Y` — plane connector prefix (`XA`/`XB` vs `YA`/`YB`) |
| `JP_G[2:0]` | Group address `g=0..7` — which HS bank this board owns |

Lines driven: \(L = 8\cdot g + k\) for \(k=0..7\).  
Full 64×64 needs every `(axis, g)` pair once: **2×8 = 16** boards, each with a unique strap (§7 roster).

**Normative group select:** hard-strap `JP_G[2:0]`; bus carries full `ADDR_NH*` / `ADDR_NL*`. The board enables its decode only when bus HS address matches the strap (on-board compare). Bring-up (`g=0` only) may share a single `DEC_EN`. Per-group firmware `DEC_EN` fan-out is a deferred alternate, not a second normative path.

### 5.2 Contents

- Decode: 74AHC138 (HS) + 74AHC238 (LS), bank enables from `J_BUS`.
- DMOS: TBD62783 (HS) + TBD62083 (LS) × FWD/REV for 8 channels.
- Steer: SS14 octal diode law ([hierarchy_abi.md](hierarchy_abi.md) **REQ-HIER-OCTAL**, 34-pin tile budget).
- `J_PLANE`: 16 signals — `{A,B}{0..7}` for this group’s lines.
- `J_BUS`: see §3.

### 5.3 Steer pin budget (one board)

Matches hierarchy_abi octal tile: **34** switch/plane pins conceptually (`HS`, `HSR`, `LS[0..7]`, `LSR[0..7]`, `A[0..7]`, `B[0..7]`). Plane-facing connector exposes the 16 A/B ends; HS/LS stay on-board to DMOS.

## 6. Bring-up wiring (8×8 = three boards)

1. One host `ccs_sense`.
2. Strap axis board A: `JP_AXIS=X`, `JP_G=0`; board B: `JP_AXIS=Y`, `JP_G=0`.
3. Cable `J_BUS` from host to both axis boards (star or short daisy).
4. Map `CCS_X` → X board pin 14; `CCS_Y` → Y board pin 14.
5. Wire X `J_PLANE` A/B[0..7] → plane `XA0..7` / `XB0..7`.
6. Wire Y `J_PLANE` similarly → `YA0..7` / `YB0..7`.
7. Wire `J_PLANE_SENSE` → plane YA/YB 65/66.
8. Apply `VDRIVE`, `+3V3`; set trimpots mid (~300 mA half-select default).

## 7. Scale-out layout (64×64 = 1 host + 2×8 axis)

Full array is **17 PCBs**: **1** × `ccs_sense` + **16** × `axis_octal` (`1 + 2×8`). Same two copper designs as bring-up; only straps and harness change. No axis-PCB redesign.

This section **describes** the 1+16 packaging contract. Coverage **PCB @ 64×64 stays `stub`** until a uniquely addressed 2×8 harness is an explicit gated claim ([coverage_matrix.md](coverage_matrix.md)). Bench / exact \(I_c\) / \(V_{drive}\) remain non-normative ([design_choices.md](design_choices.md)).

### 7.1 Board roster (straps + CCS return + plane lines)

| Board ID | Design | `JP_AXIS` | `JP_G` | `CCS_RET_AXIS` → | Plane lines \(L=8g..8g+7\) |
|---|---|---|---:|---|---|
| `HOST` | `ccs_sense` | — | — | (sources `CCS_X` / `CCS_Y` / `CCS_INH`) | Sense via `J_PLANE_SENSE` only |
| `X_g0` | `axis_octal` | X | 0 | `CCS_X` | `XA/XB0..7` |
| `X_g1` | `axis_octal` | X | 1 | `CCS_X` | `XA/XB8..15` |
| `X_g2` | `axis_octal` | X | 2 | `CCS_X` | `XA/XB16..23` |
| `X_g3` | `axis_octal` | X | 3 | `CCS_X` | `XA/XB24..31` |
| `X_g4` | `axis_octal` | X | 4 | `CCS_X` | `XA/XB32..39` |
| `X_g5` | `axis_octal` | X | 5 | `CCS_X` | `XA/XB40..47` |
| `X_g6` | `axis_octal` | X | 6 | `CCS_X` | `XA/XB48..55` |
| `X_g7` | `axis_octal` | X | 7 | `CCS_X` | `XA/XB56..63` |
| `Y_g0` | `axis_octal` | Y | 0 | `CCS_Y` | `YA/YB0..7` |
| `Y_g1` | `axis_octal` | Y | 1 | `CCS_Y` | `YA/YB8..15` |
| `Y_g2` | `axis_octal` | Y | 2 | `CCS_Y` | `YA/YB16..23` |
| `Y_g3` | `axis_octal` | Y | 3 | `CCS_Y` | `YA/YB24..31` |
| `Y_g4` | `axis_octal` | Y | 4 | `CCS_Y` | `YA/YB32..39` |
| `Y_g5` | `axis_octal` | Y | 5 | `CCS_Y` | `YA/YB40..47` |
| `Y_g6` | `axis_octal` | Y | 6 | `CCS_Y` | `YA/YB48..55` |
| `Y_g7` | `axis_octal` | Y | 7 | `CCS_Y` | `YA/YB56..63` |

Every `(axis, g)` pair appears once. `AXIS_ID0/1` stay optional and are **not** required for this roster.

### 7.2 Harness topology (`J_BUS`)

- **Full array (normative recommend):** **star** from host `J_BUS` to all sixteen axis receptacles (short equal-ish stubs). Keeps address/`VDRIVE` returns predictable under sixteen loads.
- **Bring-up (8×8):** star or short daisy between host and the two `g=0` boards is acceptable (§6).
- Keep high-current `VDRIVE` / `AGND_PWR` pairs short; treat long daisy chains as guidance to avoid, not a new electrical REQ.

CCS return harness: every X board pin 14 → host `CCS_X`; every Y board pin 14 → host `CCS_Y`. `CCS_INH` stays on the host sense/inhibit path (not on axis `J_BUS` pin 14).

### 7.3 Plane connector map

For each axis board with group `g` and local index \(k=0..7\):

| `J_PLANE` pin | Net on board | Plane net (X) | Plane net (Y) |
|---|---|---|---|
| A\(k\) | `A[k]` | `XA{L}` | `YA{L}` |
| B\(k\) | `B[k]` | `XB{L}` | `YB{L}` |

where \(L = 8\cdot g + k\). Sense/fold ends stay host-only: `J_PLANE_SENSE` → `YA65`, `YB66`, `YA66`, `YB65` (plus AGND return via bus/harness). They never appear on `axis_octal`.

```text
                    ┌─────────────────────────────────────┐
                    │  ccs_sense (HOST ×1)                │
  Pico / PIO ──────►│  ADDR, EN, VDRIVE, +3V3             │
                    │  CCS_X / CCS_Y / CCS_INH            │
                    │  sense + fold + write-back (DOUT)    │
                    └──────────────┬──────────────────────┘
                                   │ J_BUS (star @ 64×64)
          ┌────────────────────────┼────────────────────────┐
          ▼                        ▼                        ▼
   X_g0 … X_g7 (8 boards)   Y_g0 … Y_g7 (8 boards)   = 16 axis
          │                        │
          └──────────► ferrite plane XA/XB / YA/YB 0..63
                       + YA65/YB66 via HOST J_PLANE_SENSE
```

### 7.4 Assembly checklist

1. Keep the **same** `ccs_sense` host — sole ADDR / `VDRIVE` / CCS / sense / write-back board.
2. Populate and strap all sixteen axis boards per §7.1 (unique `(JP_AXIS, JP_G)`).
3. Star `J_BUS` from host to all sixteen; wire CCS returns X→`CCS_X`, Y→`CCS_Y`.
4. Wire each `J_PLANE` to the plane line range in the roster.
5. Wire `J_PLANE_SENSE` once from host to plane YA/YB 65/66.

## 8. Generation

```bash
uv run python -m generators.cli --board ccs
uv run python -m generators.cli --board axis
```

Do not hand-edit `kicad/pcb_*/` — fix generators and regenerate.

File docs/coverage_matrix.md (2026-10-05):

# Coverage Matrix

**Status:** `baseline` as the verification claim surface; gated cells are `pass` where evidence exists — remaining `stub` cells are Bench and 64×64 PCB harness  
**Owns:** scale × surface validation claims (only place allowed to assert them)  
**Does not own:** architecture invention — see [AUTHORITY.md](AUTHORITY.md)

Scale claims in this repository require an explicit row: which surfaces are validated at a given \(N \times N\). Hardware and schematic commitments must not outpace simulation capability. Process rules: [system_design_spec.md](system_design_spec.md) **REQ-SCALE-ANTIX** rule 7 and §6.

Legend: `—` not claimed; `stub` planned / described but not gated; `pass` gated green; `fail` known red. Gate IDs: **GATE-L0-PHYSICS**, **GATE-L1-CYCLE**, **GATE-L2-E2E**, **GATE-L3-SIL**, **GATE-L4-FABRIC**.

| Scale \(N\) | Schematic | PCB | SPICE (L0/L1/L2) | SIL (L3) | Bench |
|---|:---:|:---:|:---:|:---:|:-----:|
| 1 (single core) | — | — | pass (**GATE-L0-PHYSICS**) | — | — |
| 2×2 | pass (**GATE-L4-FABRIC** bring-up) | — | pass (**GATE-L1-CYCLE**, **GATE-L2-E2E**) | — | stub |
| 8×8 | — | pass (1× ccs_sense host + 2× axis_octal ERC/DRC) | — | pass (**GATE-L3-SIL**) | stub |
| 64×64 | pass (**GATE-L4-FABRIC**) | stub (1+16 layout described in [board_icd.md](board_icd.md) §7; harness not gated) | — (no Chan at n=64) | pass (**GATE-L3-SIL**) | — |

L0 evidence: `uv run pytest tests/test_l0_physics.py` (or `uv run python scripts/run_gate.py GATE-L0-PHYSICS`); model [`spice/models/chan_core.lib`](../spice/models/chan_core.lib), deck [`spice/l0/single_core.cir`](../spice/l0/single_core.cir).

L1 evidence: `uv run pytest tests/test_l1_cycle.py` (or `uv run python scripts/run_gate.py GATE-L1-CYCLE`); deck [`spice/l1/oracle_2x2.cir`](../spice/l1/oracle_2x2.cir); includes CCS-failure regression.

L2 evidence: `uv run pytest tests/test_l2_e2e.py` (or `uv run python scripts/run_gate.py GATE-L2-E2E`); deck [`spice/l2/driver_2x2.cir`](../spice/l2/driver_2x2.cir); behavioral AHC/DMOS polarity + mutex (`spice/models/dmos_ahc.lib`).

L3 evidence: `uv run pytest tests/test_l3_sil.py` (or `uv run python scripts/run_gate.py GATE-L3-SIL`); behavioral `ideal_core` + line R/L/C plant [`spice/py/l3_plant.py`](../spice/py/l3_plant.py); synthetic PIO harness [`spice/py/l3_harness.py`](../spice/py/l3_harness.py); diagonal + random sparse at n=8 and n=64 (no Chan).

L4 evidence: `uv run pytest tests/test_l4_fabric.py` (or `uv run python scripts/run_gate.py GATE-L4-FABRIC`); AST [`generators/mce_array.py`](../generators/mce_array.py); emit [`generators/emit_kicad.py`](../generators/emit_kicad.py) → [`kicad/bringup_2x2/`](../kicad/bringup_2x2/), [`kicad/driver_64x64/`](../kicad/driver_64x64/); ERC via `kicad-cli` 10.0.6 (`scripts/run_kicad_erc.py`).

Multi-board PCB: [`docs/board_icd.md`](board_icd.md) — **one** host distributes ADDR/`VDRIVE` and owns CCS/sense/write-back; axis-octal repeats (**2** @ 8×8 bring-up, **2×8 = 16** @ 64×64 with unique `g`; full roster §7). Emit `uv run python -m generators.cli --board ccs|axis` → [`kicad/pcb_ccs_sense/`](../kicad/pcb_ccs_sense/), [`kicad/pcb_axis_octal/`](../kicad/pcb_axis_octal/); `uv run pytest tests/test_board_pcb.py` / `scripts/run_kicad_board.py`. Docs describe the 1+16 layout; do **not** claim 64×64 PCB `pass` until the uniquely addressed 2×8 harness is gated. Bench stays `stub` until fab; exact \(I_c\) / \(V_{drive}\) stay non-normative ([design_choices.md](design_choices.md)).

Surfaces mean:

* **Schematic** — generated or hand-reviewed KiCad at that N (L4 prefers octal tiles / buses; see [hierarchy_abi.md](hierarchy_abi.md)).
* **PCB** — multi-board layouts (CCS+sense + axis-octal) with `kicad-cli` ERC/DRC error-clean; see [board_icd.md](board_icd.md).
* **SPICE** — L0 physics, L1 oracle, and/or L2 driver BOM decks at that N (L1/L2 stay at 2×2).
* **SIL** — L3 ideal plant + PIO/decode stimuli.
* **Bench** — physical measurements on the plane or fixture.

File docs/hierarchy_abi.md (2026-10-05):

# Hierarchical fabric ABI (steer / magnetic / DMOS)

**Status:** `baseline` (Phase 0 contract)  
**Owns:** steer/magnetic pin budgets, octal tile ABI  
**Does not own:** timing prose, BOM — see [AUTHORITY.md](AUTHORITY.md)

**REQ-HIER-OCTAL** — L4 target fabric uses octal (or equivalent) tiles + buses; monolithic 256-end sheets are not the long-term ABI.

**Problem this solves:** The physical plane has **256** drive ends (64× XA/XB/YA/YB). If steer and magnetic sheets each expose every A/B end as hierarchical pins, pin counts explode (on the order of **320** steer pins + **258** magnetic pins, with ~**512** duplicated root instances). That budget is hostile to KiCad hierarchy, ERC, and agent-driven generation—and it tempts full-fidelity SPICE at the wrong scale.

**Rule:** hierarchical boundaries match a manufacturing-friendly pin budget and the **bank-level** control plane, not a flat 256-pin root. Simulation scale follows the L0–L4 dial in [system_design_spec.md](system_design_spec.md) (**REQ-SCALE-ANTIX**). Naming: [naming.md](naming.md).

## Target naming

| Artifact | Name | Role |
|---|---|---|
| Preferred steer fabric | `steer_octal_{X,Y}_g{0..7}.kicad_sch` | One HS group × one axis (FWD+REV) |
| Optional finer grain | `steer_line` | One line, 4 diodes, 6 pins |
| Magnetic fabric | `magnetic_plane.kicad_sch` (generated) | Weave from AST; bus pins on root |
| Not the long-term ABI | Monolithic `steer_64` | Acceptable only as a temporary experiment; not the L4 target |

## Pin budgets

| Boundary | Monolithic (avoid as target) | Octal tiles (target) | Line tiles (alt) |
|---|---:|---:|---:|
| Steer sheet pins | ~320 (64 switch + 256 plane) | 34 per octal × 16 sheets | 6 per line × 128 |
| Magnetic sheet pins | ~258 | Prefer `XA[63:0]`… buses on root | same |
| Root plane pin instances | ~512 (Steer + Magnetic duplicated) | Wire buses once; tiles bind locally | same |

### Octal tile pin list (one axis, one HS group `g`)

Lines \(L = 8\cdot g + k\) for \(k = 0\ldots7\).

| Pin | Count | Nets |
|-----|---:|---|
| `HS`, `HSR` | 2 | `{axis}HS{g}`, `{axis}HS{g}R` |
| `LS[0..7]`, `LSR[0..7]` | 16 | `{axis}LS{k}`, `{axis}LS{k}R` |
| `A[0..7]`, `B[0..7]` | 16 | `{axis}A{L}`, `{axis}B{L}` |
| **Total** | **34** | — |

Diode law:

```text
FWD:  HS  → diode → B{line}
      A{line} → diode → LS{ls}
REV:  HSR → diode → A{line}
      B{line} → diode → LSR{ls}
```

Octal tile emitters live in [`generators/emit_kicad.py`](../generators/emit_kicad.py) (AST: [`generators/mce_array.py`](../generators/mce_array.py)). Do not hand-edit generated sheets.

### Line tile pin list (optional finer grain)

| Pin | Role |
|-----|---|
| `HS`, `LS`, `HSR`, `LSR` | Switch nodes for this line’s group |
| `A`, `B` | Plane ends |

Four SS14s inside. Root or octal parent binds group fan-out.

## Decode and DMOS (control side)

| Block | Pin budget intent |
|---|---|
| `decode_block` | 8 HS + 8 LS bank outs per axis/direction — **not** 64 line pins |
| DMOS array (TBD62783 / TBD62083) | 8-channel atom matching one decode bank group |
| Sense / fold | Outside Drive/Decode entirely |

Do **not** resurrect per-line TC4427 + discrete MOSFET `drive_block` × 32 as the primary hierarchical ABI. That path multiplies sheets and still dumps plane ends onto steer.

## Magnetic plane

1. **Layout / net semantics:** generated 64×64 magnetic sheet from the weave AST ([`generators/mce_array.py`](../generators/mce_array.py) → `magnetic_plane.kicad_sch`).
2. **SPICE scale proof:** L3 behavioral `ideal_core`, not 4,096 detailed Chan/`coremem` instances.
3. **Root ABI:** prefer KiCad buses `XA[0..63]`, `XB[0..63]`, `YA[0..63]`, `YB[0..63]` plus `YA65` / `YB66`. Do not duplicate 256 hierarchical stubs on both Steer and Magnetic if a single bus vector can feed both.

Fold `YA66`═`YB65` stays **local** on the magnetic sheet (`SENSE_FOLD`); it is not a Drive/Decode hierarchical pin.

## Target sequence (redux)

| Step | Action |
|---|---|
| 1 | Freeze naming + this ABI in docs (Phase 0) |
| 2 | Prove L1/L2 at n=2 with DMOS BOM; freeze decode/DMOS pinouts |
| 3 | L3 ideal n×n without Chan at scale |
| 4 | Emit octal steer tiles + bus-rooted magnetic fabric from AST (L4) |
| 5 | Never promote monolithic 256-end sheets as the long-term fabric |

## What never enters Drive/Decode

`YA65`, `YB65`, `YA66`, `YB66`, `SENSE_FOLD` — sense/fold only ([naming.md](naming.md) §8).

## Multi-board packaging

Physical split: **one** CCS/sense host (ADDR + `VDRIVE` distribution, CCS, sense, write-back) plus repeated **axis-octal** PCBs — bring-up 2 boards (`g=0`), full array **2×8** with unique group address. Connector pinouts and 1+16 roster: [board_icd.md](board_icd.md) §7. Do not invent a second electrical pin list here.

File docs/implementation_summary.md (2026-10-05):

# Target Block Architecture (Sketch)

**Status:** `sketch` (non-authoritative)  
**Must not override** owners in [AUTHORITY.md](AUTHORITY.md).

Intended hierarchical fabric sketch. Generated KiCad lives under [`kicad/`](../kicad/) from [`generators/`](../generators/) (**GATE-L4-FABRIC**); this file remains non-authoritative.

Normative contracts: [system_design_spec.md](system_design_spec.md). Naming / ABI: [naming.md](naming.md). Pin budgets: [hierarchy_abi.md](hierarchy_abi.md). BOM: [component_selection.md](component_selection.md). Coverage: [coverage_matrix.md](coverage_matrix.md).

## Architecture

Three-wire cores (X, Y, sense)—no separate inhibit winding. Sense/inhibit is two independent loops (`YA65`↔`YA66`, `YB65`↔`YB66`), joined on the driver at **`YA66`═`YB65`**. Outer ends `YA65`/`YB66` are shared for differential READ and series inhibit. Drive is coincident half-select into two sinks (`CCS_X`, `CCS_Y`), with inhibit on its own sink (`CCS_INH`). Forward DMOS arrays do READ (−Ic/2); reverse arrays do WRITE (+Ic/2).

```
ADDR_XH/XL[2:0] ──┐
DEC_EN / FWD_EN_n ┼── Decode Block (N=axis, n=bank)
│   138 + 238; four root calls (X/Y, FWD/REV)
▼
X_HS{0..7}_n / X_LS{0..7}_en
│
▼
DMOS Array Block
TBD62783 (HS) / TBD62083 (LS); SS14s on steer tiles
└────────┬─────────┘
▼
CCS_X / CCS_Y / plane
│
YA65/YB66 sense + inhibit
```

**Fail-safe (target):** `DEC_EN` pull-down (off); `FWD_EN_n` / `REV_EN_n` pull-up (inactive). Disabled **138** outputs HIGH → TBD62783 sources OFF. Disabled **238** outputs LOW → TBD62083 sinks OFF. HS inputs `*_n` have 10k pull-ups; LS inputs `*_en` have 10k pull-downs. Never assert both bank enables.

## Intended blocks

| Block | What it does |
|---|---|
| Sense | 1k iso, BAT54S, TLV3501 → 74AHC74 |
| Magnetic Cores | Generated 64×64 weave fixture; center tap `SENSE_FOLD` (`YA66`═`YB65`). 2×2 archived rule is the bring-up stand-in |
| CCS | ×3 (X, Y, inhibit): TL431 + 3296W → OPA192 → IRLZ44N + 1Ω; pin `CCS_RET` |
| Drive arrays | TBD62083/TBD62783 8-channel DMOS |
| Steer | **L4 target:** octal tiles ([hierarchy_abi.md](hierarchy_abi.md)). Monolithic `steer_64` is not the long-term ABI |
| Inhibit | Discrete driver on the folded sense path |
| Decode | One axis 138+238; pins `N_HS{0..7}_n` / `N_LS{0..7}_en`; four root calls (X/Y × FWD/REV) |
| Decode CTRL | Address + enable headers; root binds X/Y and `FWD_EN_n` / `REV_EN_n` |

## Decode map (one axis)

| Ref | Part | Role | ADDR | Hier outs |
|-----|---|---|---|---|
| U11 | 74AHC138 | HS | `ADDR_NH[2:0]` | `N_HS0_n` … `N_HS7_n` |
| U12 | 74AHC238 | LS | `ADDR_NL[2:0]` | `N_LS0_en` … `N_LS7_en` |

**Line select:** \(Nn = 8\cdot HS + LS\). Root maps X FWD: `ADDR_NH*`←`ADDR_XH*`, `BANK_EN`←`FWD_EN_n`, outs → `X_HS*_n` / `X_LS*_en`.

## Component selection (as targeted)

### Address decode and DMOS arrays

| MPN | Role | Notes |
|-----|---|---|
| 74AHC138 | Decode HS | Active-low Y → TBD62783 sources |
| 74AHC238 | Decode LS | Active-high Y → TBD62083 sinks |
| TBD62783 | DMOS source array | High-side drive |
| TBD62083 | DMOS sink array | Low-side drive |

See [component_selection.md](component_selection.md) §1.

### Drive matrix / CCS / Sense

SS14 on steer tiles; CCS (TL431, OPA192, IRLZ44N); Sense (TLV3501, BAT54S, 74AHC74, 1k iso). Soft mid on magnetic sheet. DC-coupled Sense locked.

## Bench cycle (target)

After CCS setpoint:

1. Assert `DEC_EN` and pulse `FWD_EN_n` → READ (−Ic/2)
2. SENSE STROBE → latch DOUT
3. Inhibit (`INH_EN_n`) if restoring/writing 0
4. Pulse `REV_EN_n` → WRITE (+Ic/2)

Plane hookup: `XA*`/`XB*`/`YA*`/`YB*` 0…63 through steer tiles to buses. Sense/inhibit outer ends `YA65`/`YB66`; center tap `YA66`═`YB65` (`SENSE_FOLD`, 10 kΩ to AGND). SPICE e2e stays on the 2×2 ladder until an L3 ideal deck is gated—see [coverage_matrix.md](coverage_matrix.md).

## Array model (target)

* **Loop A:** `(x+y)` even, 2,048 cores. 2×2 stand-in: `YA65` ↔ MCE11 ↔ MCE00 ↔ `YA66`.
* **Loop B:** `(x+y)` odd, the other 2,048. 2×2 stand-in: `YB65` ↔ MCE10 ↔ MCE01 ↔ `YB66`.
* **Center tap:** `YA66`═`YB65`, 10 kΩ→AGND. The plane does not join the loops.
* **Outer ends:** `YA65` / `YB66` for differential READ and series inhibit.

The real plane’s geographic sense split may still need tracing; the checkerboard rule above is the schematic stand-in. Weave AST geometry SSOT: [`generators/mce_array.py`](../generators/mce_array.py).

## Still deferred (not SSOT status)

This sketch must not override owners. Remaining gaps vs the gated tree:

- RP2040 PIO firmware (L3 SIL uses *synthetic* PIO stimuli today)
- Decoder / DOUT LEDs (optional; [design_choices.md](design_choices.md))
- Bench calibration of \(I_c\), inhibit polarity, weave L/DCR
- 64×64 PCB harness claim (1+16 layout is documented in [board_icd.md](board_icd.md) §7; coverage PCB cell stays `stub`)

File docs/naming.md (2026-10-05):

# Signal naming and hierarchical scale path

**Status:** `baseline` (Phase 0 contract)  
**Owns:** net grammar, naming layers, decode/DMOS call model  
**Does not own:** pin-budget tables — see [hierarchy_abi.md](hierarchy_abi.md); authority map: [AUTHORITY.md](AUTHORITY.md)

Physical connector contract: [design_specification.md](design_specification.md). Process and anti-explosion rules: [system_design_spec.md](system_design_spec.md).

**Rule:** the hierarchical sheet is a *function*; root wires are the *call arguments*. Define logic once; instantiate and scale with buses and layout replication.

## 1. Three naming layers

| Layer | What it is | Drive lines | Sense / fold |
|---|---|---|---|
| **Physical** | Stamped on the plane PCB | Contacts **1–64** on XA/XB/YA/YB | Y contacts **65**, **66** |
| **Syntax** | Nets / code / KiCad hierarchy | `XA0`…`XA63` (0-based); block tokens `N`/`n` | `YA65`…`YB66` — **outside** Drive/Decode sheet pins |
| **Semantic** | Function | Half-select matrix | READ pickup + inhibit fold — **not** drive lines |

Map: physical contact \(p\) ↔ logical index \(p-1\). Never invent drive net `XA64`. Never put 65/66 in the Drive/Decode pin chain.

## 2. Gate / enable nets (matrix control)

Format: `[N]_[func][n][dir]_[logic]`

| Token | Meaning | Valid values |
|---|---|---|
| `N` | Axis | `X`, `Y` |
| `func` | Hardware role | `HS` (high-side), `LS` (low-side) |
| `n` | Index | Line `0`…`63`, or decode bank `0`…`7` |
| `dir` | Drive direction | omit = FWD/READ; `r` = REV/WRITE |
| `logic` | Active level | `_n` = active-low; `_en` = active-high (always explicit) |

**Examples:** `X_HS0_n`, `X_LS0_en`, `X_HS0r_n`, `Y_HS3r_n`.

**REQ-NAME-GATE** — audit regex (gate nets; single home):

```text
^[XY]_(HS|LS)[0-9]{1,2}r?_(n|en)$
```

## 3. Plane drive nets

Format: `[N][end][n]`

| Token | Meaning | Values |
|---|---|---|
| `N` | Axis | `X`, `Y` |
| `end` | Connector side | `A` (one end of the line), `B` (other end) |
| `n` | Logical line | `0`…`63` |

Examples: `XA0`, `XB0`, `YA17`, `YB63`. Physical contact number = \(n+1\).

## 4. Global and special nets

| Class | Nets |
|---|---|
| Enables | `FWD_EN_n`, `REV_EN_n`, `INH_EN_n`, `DEC_EN` |
| Analog / power | `VDRIVE`, `CCS_X`, `CCS_Y`, `CCS_INH`, `AGND`, `+3V3` |
| Sense / fold (not Drive/Decode hierarchy) | `YA65`, `YB65`, `YA66`, `YB66`, `SENSE_FOLD` |

Fold model: two independent loops `YA65`↔`YA66` and `YB65`↔`YB66`. The plane does not join them. Schematic center-tap node is **`SENSE_FOLD`**: `YA66` tied to `YB65`, soft ground 10 kΩ→AGND. Outer ends: `YA65` / `YB66`. See [theory_of_operation.md](theory_of_operation.md).

Historical aliases (do not invent new uses): `SENSE_P` / `SENSE_N` mean the differential outer ends **`YA65` / `YB66`**. `+5V` is not part of the multi-board host/`J_BUS` rail set (`+3V3` + `VDRIVE` only).

### 4.1 PCB / control-bus layer

Multi-board packaging nets ([board_icd.md](board_icd.md)); pin tables stay there — this section only names the grammar bridge.

| Board / bus net | Role | Fabric / ICD alias |
|---|---|---|
| `ADDR_NH0..2` | HS / group address on `J_BUS` | Same bits as hierarchical `ADDR_NH[2:0]` (parent `ADDR_XH*` / `ADDR_YH*`) |
| `ADDR_NL0..2` | LS address on `J_BUS` | Same bits as hierarchical `ADDR_NL[2:0]` (parent `ADDR_XL*` / `ADDR_YL*`) |
| `CCS_RET_AXIS` | Axis board CCS return (harness → `CCS_X` or `CCS_Y`) | Not a fabric hierarchical pin |
| `DOUT` | Write-back latch output (host only) | Host sense path |
| `SENSE_STROBE` / `PIO_STROBE` | Strobe into sense latch (host / Pico) | Timing aperture |
| `INH_POL_SEL` / `JP_INH_POL` | Inhibit polarity board select (host) | [design_choices.md](design_choices.md) |
| `AXIS_ID0/1` | Optional ID straps | Not required for 1+16 roster |
| `JP_AXIS`, `JP_G[2:0]` | Axis and group straps on each `axis_octal` | Select method: [board_icd.md](board_icd.md) §5.1 |

## 5. Hierarchical block ABI (reusable sheets)

Parent nets use §2–§4. **Inside** reusable sheets, pins stay parameterized with **`N`** (axis) and **`n`** (bank or group).

### Decode Block — target `decode_block.kicad_sch`

One axis: 74AHC138 HS + 74AHC238 LS. Hierarchical pins:

| Pin | Role | Example parent (X FWD) |
|-----|---|---|
| `ADDR_NH[2:0]` / `ADDR_NL[2:0]` | Bank address | `ADDR_XH*` / `ADDR_XL*` |
| `BANK_EN` / `DEC_EN` | Bank / chip enable | `FWD_EN_n` / `DEC_EN` |
| `N_HS{0..7}_n` | HS outs | `X_HS0_n` … `X_HS7_n` |
| `N_LS{0..7}_en` | LS outs | `X_LS0_en` … `X_LS7_en` |

`line# = 8·HS + LS` (logical 0…63). Control stays at bank level (8+8), never 64 line pins per axis.

**L2 freeze (GATE-L2-E2E):** behavioral n=2 sim confirms this pin polarity and FWD/REV mutex — `FWD_EN_n` / `REV_EN_n` active-low with mutual exclusion, `DEC_EN` active-high, 138 outs active-low into TBD62783, 238 outs active-high into TBD62083. Evidence: [`spice/l2/driver_2x2.cir`](../spice/l2/driver_2x2.cir), [`tests/test_l2_e2e.py`](../tests/test_l2_e2e.py). Full 8-channel sheet pin lists above remain the schematic ABI target.

### DMOS array block — target drive atom

One 8-channel Toshiba DMOS package (or a small sheet that wraps one): TBD62783 (HS sources) or TBD62083 (LS sinks). This replaces the old per-line TC4427 + discrete MOSFET `drive_block` as the **primary** ABI.

| Pin class | Role | Example parent |
|---|---|---|
| `N_HS{0..7}_n` or `N_LS{0..7}_en` | Logic inputs from decode | `X_HS0_n` … / `X_LS0_en` … |
| Switch nodes (group) | High-current outputs toward steer | `XHS{g}` / `XLS{k}` (naming frozen at L2) |
| `VDRIVE` / return | Rails | `VDRIVE`; parent binds axis CCS as needed |

SS14 steering diodes live in steer tiles ([hierarchy_abi.md](hierarchy_abi.md)), not inside decode.

### Decode CTRL — target `decode_ctrl` / `decode_ctrl_y`

Address and bank-enable headers. Hierarchical pins are the function; root labels are the arguments. One axis of address per sheet; enable headers exist once (not cloned per axis).

| Pin | Role | Example parent |
|-----|---|---|
| `ADDR_NH[2:0]` | HS address | `ADDR_XH*` / `ADDR_YH*` |
| `ADDR_NL[2:0]` | LS address | `ADDR_XL*` / `ADDR_YL*` |
| `BANK_EN` | Bank enable, pull-up inactive | `FWD_EN_n` |
| `DEC_EN` | Chip enable, pull-down off | `DEC_EN` |
| `REV_EN_n` | Reverse bank enable, pull-up inactive | `REV_EN_n` |

## 6. Hierarchy as function call / instance

```mermaid
flowchart LR
  DecodeCTRL[Decode_CTRL]
  DecodeBlock[decode_block]
  DmosArray[DMOS_array_8ch]
  Steer[steer_octal_tiles]
  Plane[XA_XB_YA_YB_buses]

  DecodeCTRL -->|"ADDR FWD_EN_n"| DecodeBlock
  DecodeBlock -->|"X_HS0_7_n X_LS0_7_en"| DmosArray
  DmosArray --> Steer --> Plane
```

1. **Define once** — `decode_block`, DMOS array sheets, `decode_ctrl` with `N`/`n` hierarchical pins.
2. **Instantiate on root** — four `decode_block` calls (X/Y × FWD/REV); DMOS arrays receive bank buses; steer octal tiles bind to plane buses. FWD sources one plane end and sinks the other; REV swaps ends.
3. **Scale with buses** — root uses KiCad buses such as `X_HS[0..7]_n`, `X_LS[0..7]_en`, and `XA[0..63]` so the top sheet stays thick vectors, not hundreds of stubs.
4. **PCB multiplier** — route one DMOS/steer tile cleanly, then **Replicate Layout** for the remaining groups. Hierarchy makes instance membership unambiguous for the plugin.

## 7. Scale roadmap (as-gated)

Aligned with [coverage_matrix.md](coverage_matrix.md) and [AUTHORITY.md](AUTHORITY.md) Layer D — not a future-only sketch.

| Step | Schematic | SPICE / SIL | PCB |
|---|---|---|-----|
| Done | 4× `decode_block`, DMOS 8-ch arrays, octal steer tiles; fabric AST → KiCad (`bringup_2x2`, `driver_64x64`) | L0–L2 on 2×2; L3 ideal n×n | Single-board emit: `pcb_ccs_sense` + `pcb_axis_octal` (8×8 bring-up ERC/DRC) |
| Next | Buses on root (already preferred ABI) | PIO firmware on ideal plant (still deferred) | Replicate layout; gate 1+16 harness before 64×64 PCB claim |
| Later | — | Bench-calibrated L0/L3 | Full 1+16 harness + fab |

Layer contracts: [system_design_spec.md](system_design_spec.md). Multi-board roster: [board_icd.md](board_icd.md) §7.

## 8. What never enters the Drive/Decode chain

`YA65`, `YB65`, `YA66`, `YB66`, and `SENSE_FOLD` are sense/fold only. They may appear as local labels on the magnetic sheet or as Sense/Inhibit hierarchical pins, but they are **not** drive switch nodes and are **not** decode outputs.

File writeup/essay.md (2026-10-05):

# A record of the driver, so far

This is a snapshot of a ground-up magnetic core memory driver and the digital twin that is being built beside it. The plane is a 64×64 ferrite array. The work is a rewrite, arranged so an agent can move against a frozen contract and a simulator. Three things count as done, when they are done: the process, the circuit, and the documentation of both. This essay is only the telling of where that stands on 4 October 2026.

The figures below were rendered that day on a machine named hellway, from the same stimuli the gate tests already run. The samples quoted in the text are in [figures/results.json](figures/results.json). Drive current in these decks is a simulation assumption, \(I_c = 600\,\mathrm{mA}\) so \(I_c/2 = 300\,\mathrm{mA}\). The exact operating current is still an open bench question; the owner for that list is [docs/design_choices.md](../docs/design_choices.md).

If a sentence here and an owner document disagree, the owner wins. This folder does not feed the design.

## The array, in one sitting

Each core sits at a crossing of an X wire and a Y wire. A full write or a destructive read wants about \(I_c\) through that one core. The driver puts \(I_c/2\) on one X line and \(I_c/2\) on one Y line. Only the intersection sees the full current. Every other core on those two lines is half-selected, and a half-selected core has to keep its bit.

The cores on this plane are three-wire. There is no separate inhibit winding. The sense wire does both jobs, at different times. During a read it is a millivolt pickup. During a write of zero it carries \(I_c/2\) in series, opposing the write so the selected core stays at zero. The plane folds that sense path outside the array: two loops joined by a jumper, so one comparator and one inhibit driver can see the whole weave. A read to one destroys a stored one, so every access is a read, then a write that puts the bit back, or writes the new one. The sense strobe has to land in a quiet window after the read edge and before the inhibit and write edges, on the order of 150–300 ns into the read.

That is the whole machine the rest of this record is trying to drive. The contract for the fold, the sense path, and the timing lives in [docs/design_specification.md](../docs/design_specification.md). A shorter teaching pass is [docs/theory_of_operation.md](../docs/theory_of_operation.md).

## Working with agents

The method is a box around the agent. Each kind of fact has one owner. Plane geometry, net names, the bill of materials, pin budgets, open decisions, and scale claims live in different files, and the map of who owns what is [docs/AUTHORITY.md](../docs/AUTHORITY.md). Downstream text links to the owner. It does not grow a second copy of the fold, the part numbers, or the gate criteria.

When two owners seem to conflict, the work stops and a person decides. Chat is a scratchpad. A scale claim is allowed to appear in one place, the coverage matrix, and only after a run has earned the cell. That is how an agent is kept from inventing a third architecture in the middle of a task: the next sentence has to land in a document that already has a job, or it does not land.

The practical shape of a task is therefore small. Read the map, open the owner for the fact at hand, change that fact or the simulation that checks it, and leave the other documents alone. The coverage matrix, as of this record, says a single core and the 2×2 driver path have passed in SPICE, and the ideal plant has passed at 8×8 and 64×64. The generated schematic has passed at 2×2 and at 64×64. The two board designs have passed ERC and DRC at the 8×8 bring-up quantity. The 64×64 board harness and the bench column are still empty. Those sentences are the matrix’s, in [docs/coverage_matrix.md](../docs/coverage_matrix.md).

## Simulation in the loop

A nonlinear ferrite model of all 4,096 cores will not finish inside a loop an agent can wait on. The ladder answers one question at a time, on the smallest plant that can answer it.

```mermaid
flowchart LR
  L0[L0 one Chan core]
  L1[L1 2x2 cycle]
  L2[L2 address path at n equals 2]
  L3[L3 ideal core at N]
  L4[L4 octal fabric and boards]
  L0 --> L1 --> L2 --> L4
  L1 --> L3 --> L4
```

L0 asks whether the physics we are willing to trust can hold a half-select, tell a stored one from a stored zero on a destructive read, and accept a write-back. It is one core, a Chan-threshold subcircuit, and it stays small: at most sixteen instances, and never the proof at n=64.

L1 asks whether four cores, wired as a 2×2 with the external sense fold, can run a full write, read, inhibit, and restore, and whether a failed current source on one axis leaves the addressed core alone. The switches here are ideal.

L2 asks the same cycle with the address pins in the path: decode, the forward and reverse banks, and the DMOS polarity the board will actually use. It still sits on the 2×2. It checks that both banks asserted together produce no drive, that an idle enable produces no drive, and that the strobe window still sees the destroyed bit while the bank is on.

L3 asks whether a whole matrix can be walked. The core there is a threshold law: full-select flips, half-select holds, a destructive read of a one emits a fixed sense pulse. Each line carries a lumped resistance, inductance, and capacitance, and the plant waits out that settle before it treats the bit as valid. Stimuli are a synthetic stand-in for the PIO sequence. Patterns are a full diagonal and a random sparse set, at 8 and at 64, plus a few hundred continuous cycles at 64. Chan stays behind, on L0.

L4 asks whether that same driver can be drawn as sheets and as two boards without making the 256 drive ends into 256 pins. It is KiCad, emitted from the weave, and checked by `kicad-cli` 10.0.6. The bench is still later. The rules for the ladder, and the reason the 256 drive ends are not the unit of simulation or of a hierarchical sheet, are in [docs/system_design_spec.md](../docs/system_design_spec.md) and [docs/hierarchy_abi.md](../docs/hierarchy_abi.md).

Each layer is a pytest module. A thin wrapper, `scripts/run_gate.py`, runs one gate by name. A green run is what turns a coverage cell from a plan into a pass. The essay does not add a new test. It replays the ones that already exist and draws them.

## What the runs show

### One core

The first question is half-select. Both axes carry 300 mA together, which is a full-select write, and the remanent state sits at +1. Then only one axis carries 300 mA. The magnetomotive force during that second pulse is 0.300 A, and the state afterward is still +1. The shaded band in the figure is that one-axis pulse.

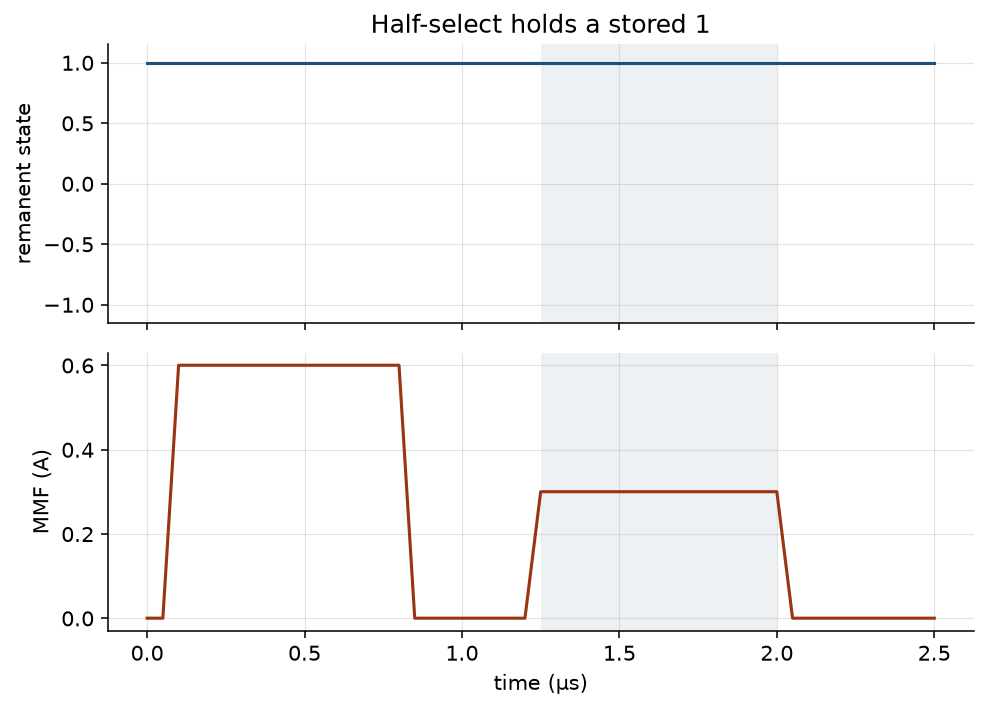
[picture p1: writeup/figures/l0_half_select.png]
Half-select holds a stored 1. The shaded band is a single axis at 300 mA.


The second question is whether a read can tell the bits apart. A stored one, read with both axes at −300 mA, produces a sense spike of 40.0 V inside the read window and leaves the state at −1. The same read of a stored zero, in that same window, produces a sense peak of \(4 \times 10^{-15}\,\mathrm{V}\), which is numerical zero. The early spike on the stored-zero trace is the write that put the zero there, starting from a stored one; the shaded band is the read, and that read is quiet.

The 40 V figure is the model’s sense node. A flux scale inside the Chan subcircuit sets the height of these numerical peaks. The gate asks for discrimination: the stored-one peak has to dwarf the stored-zero peak. It does. A bench measurement on the real plane will be millivolts, and this plot is not that measurement.

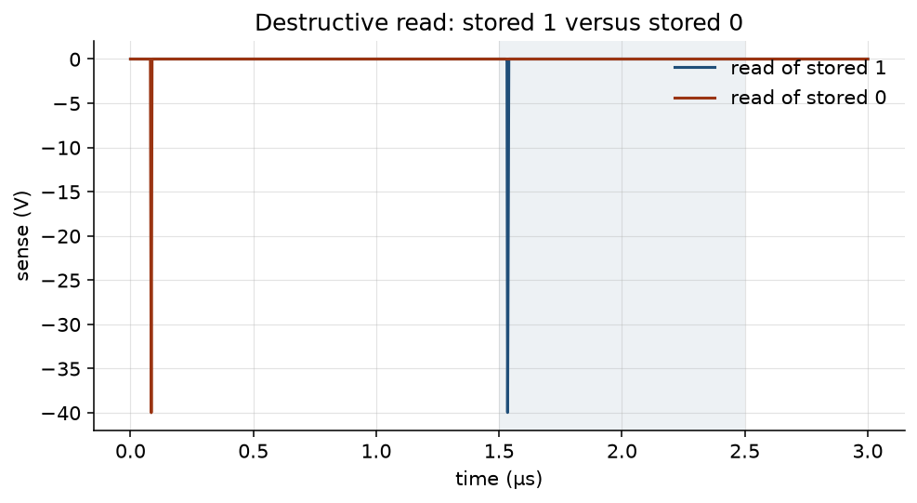
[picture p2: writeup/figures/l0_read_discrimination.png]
Destructive read of a stored 1, over the same current shape used to read a stored 0.


The third question is restore. The core is written to +1, read back through zero to −1, and written again to +1. Sampled after each phase, the state is +1, then −1, then +1.

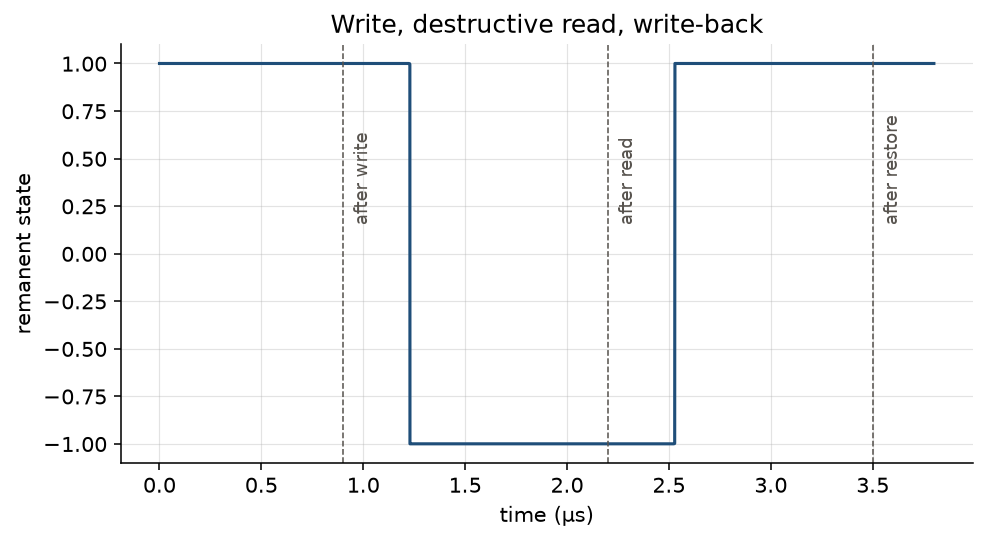
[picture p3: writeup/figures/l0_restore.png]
Write, destructive read, and write-back on one core.


### A 2×2 cycle

Four cores share the fold. The addressed core is (0,0). The run writes a one, reads it, drives the inhibit current through the sense path, and writes the one back.

After the write, (0,0) is at +1. The two half-selected neighbors, (0,1) and (1,0), stay at −1, and so does the unselected core; on the plot those three traces lie on top of each other. The read drives the addressed core to −1 and puts a 40.0 V spike on the sense node, same numerical sense scale as the single core. During inhibit the addressed magnetomotive force is 0.300 A, the half-current on the sense wire, and the core stays at the zero the read just wrote. The restore returns (0,0) to +1.

The bands on the figure are the four phases: write, read, inhibit, restore.

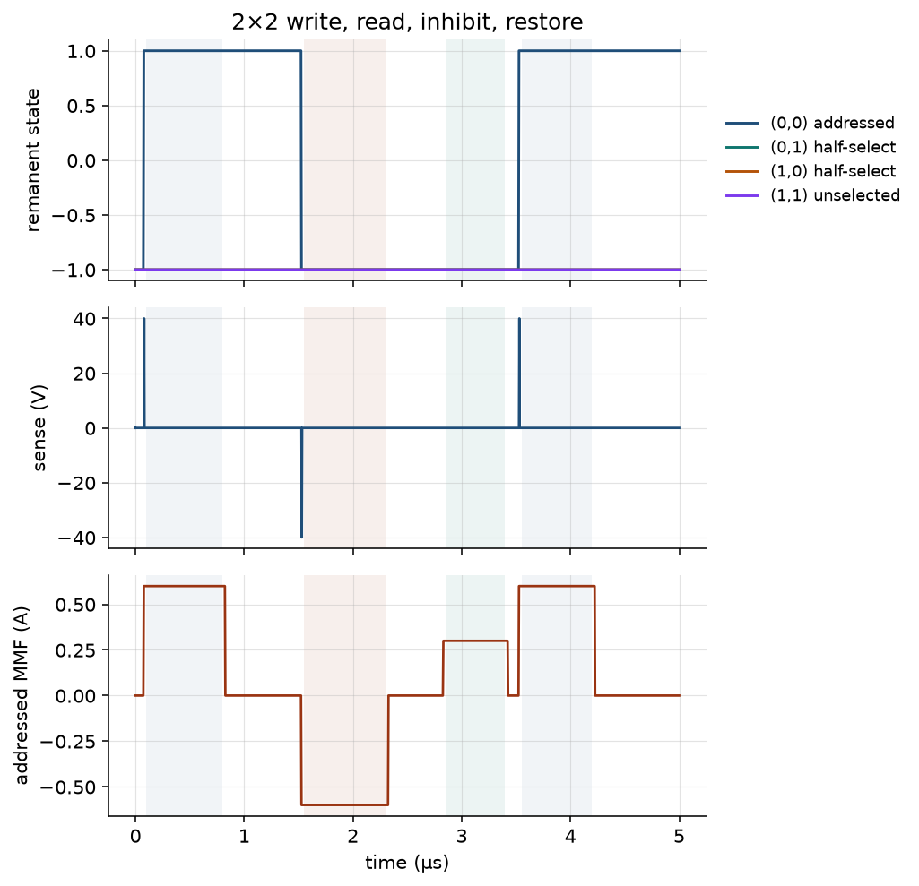
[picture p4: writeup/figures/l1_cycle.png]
Four cores through write, read, inhibit, and restore. Neighbors stay at −1.


The regression that has to keep passing is a broken X source. Y is enabled, X is open, and the addressed core starts as a stored one. A single axis must not flip it. After the pulse, (0,0) is still at +1.

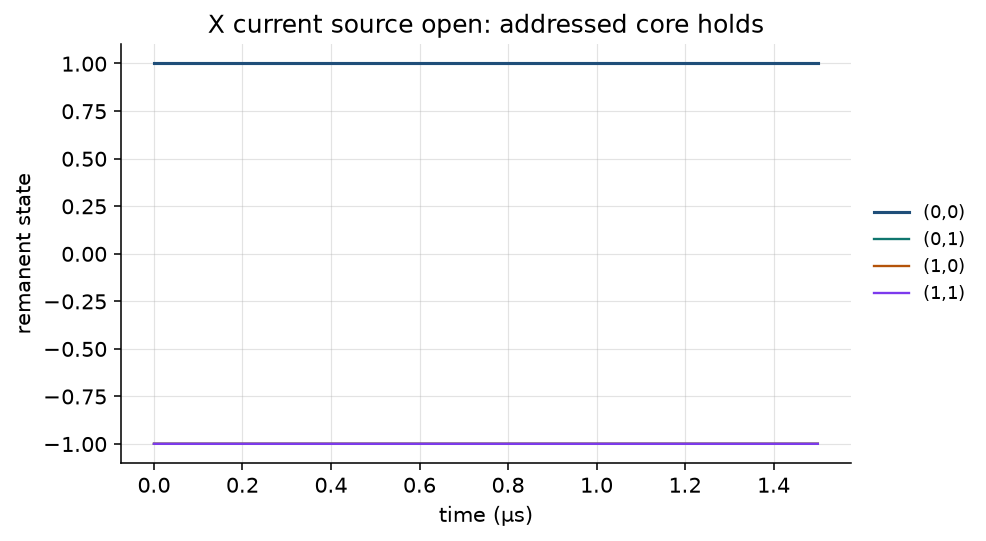
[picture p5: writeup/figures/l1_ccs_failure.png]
With the X current source open, the addressed core holds its stored 1.


### The address path

L2 keeps the 2×2 and inserts the decode path in front of it. Address (0,0), a reverse-bank write, then a forward-bank read. After the write, (0,0) is +1 and the half-selected neighbors are still −1. After the read, (0,0) is −1. The sense spike on that read is 40.0 V, again the model node, sitting on the leading edge of the forward pulse.

The dashed line is the strobe, 1.75 µs, which is 200 ns after the read edge. At that instant the addressed state is already −1, and the X line enable is still 1. The bit is valid while the bank is still on. That is the window the timing contract is trying to protect.

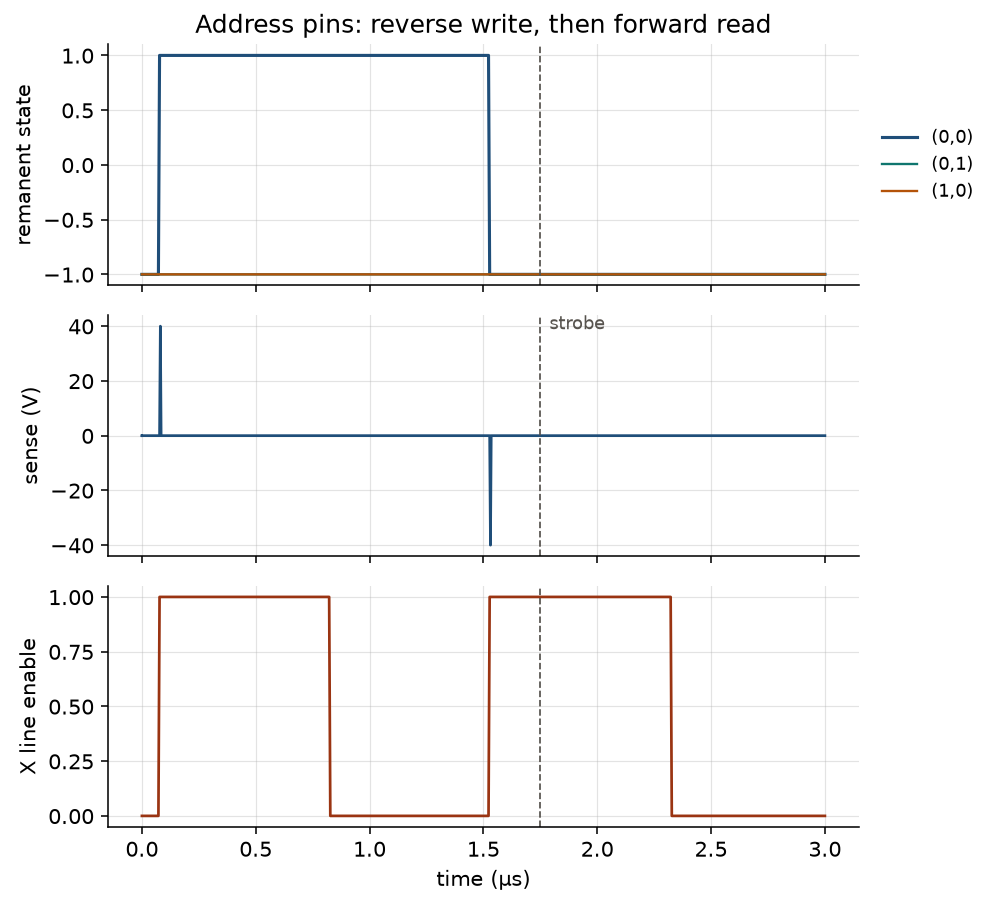
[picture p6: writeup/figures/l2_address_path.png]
Reverse write, then forward read, with the strobe marked 200 ns into the read.


The mutex is the fail-safe. Forward and reverse are both asserted, with decode enabled. The X line enable stays at 0, and a stored one on (0,0) is still +1 at the end of the run. An idle enable, covered by the same gate and not drawn here, does the same thing: no drive, core holds.

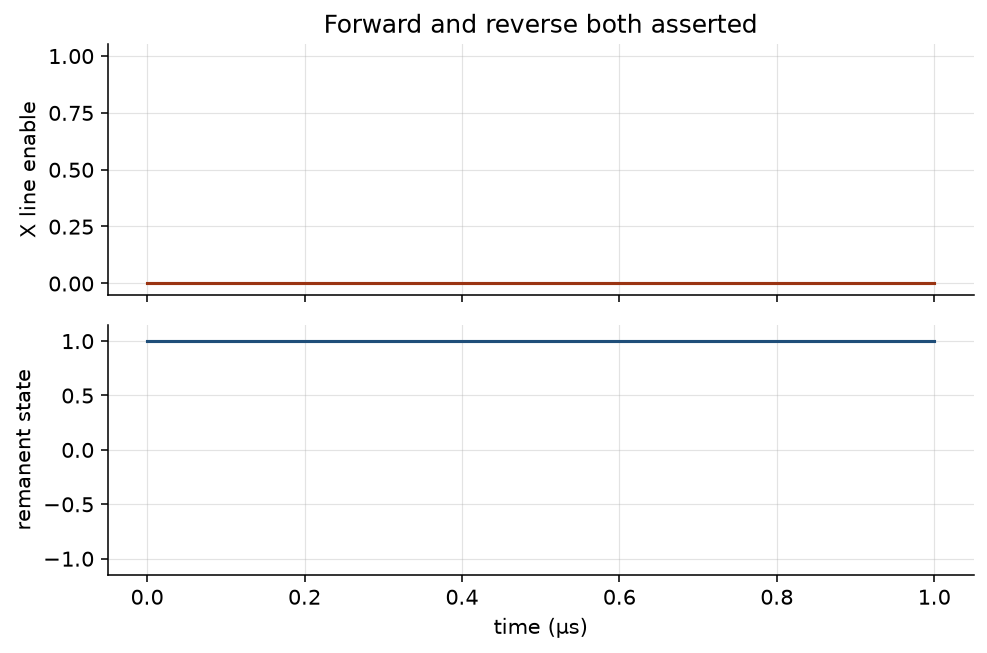
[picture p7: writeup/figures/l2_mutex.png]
Both banks asserted: the line enable stays off and the core holds.


### The full matrix, idealized

L3 does not have a SPICE waveform to show. The plant applies settled currents after a lumped line delay, then updates a threshold core. The honest pictures are the array and the clock.

An 8×8 written with ones on the diagonal and zeros elsewhere holds exactly eight ones, on that diagonal. The same plant, the same write, is what runs at 64×64. The small map is the one a person can read.

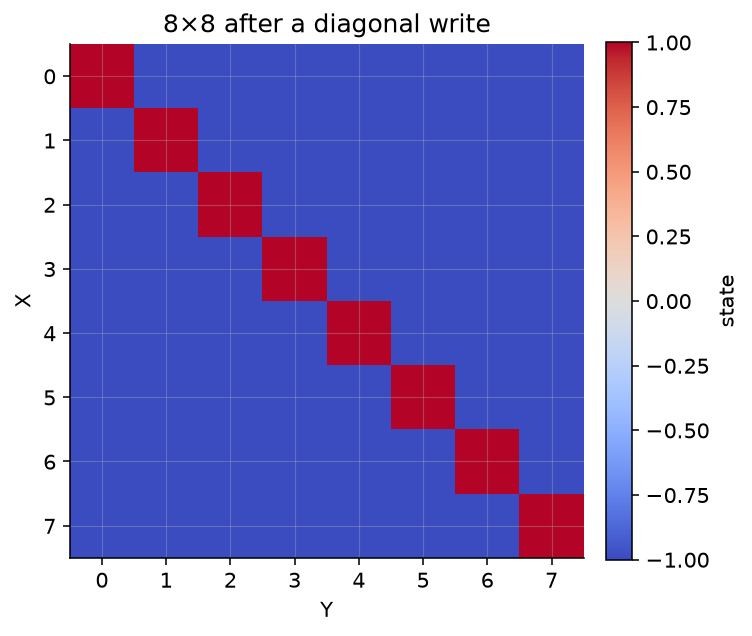
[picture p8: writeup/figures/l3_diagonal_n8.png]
8×8 ideal cores after a diagonal write. Stored 1 is the warm diagonal.


Wall time on hellway, for the same workloads the gate runs:

| Run | Wall time |
|-----|---:|
| 8×8 diagonal, every cell written and checked | 2.69 ms |
| 8×8 sparse, 16 cells, seed 42 | 0.48 ms |
| 64×64 diagonal, every cell written and checked | 3.68 s |
| 64×64 sparse, 64 cells, seed 7 | 32.0 ms |
| 64×64, 500 random cycles, seed 3 | 182 ms |

The long bar is the full diagonal at 64, because that walk touches all 4,096 cores twice: a write, then a read and restore. The 500-cycle run is a thin sample of the same plant, which is why it finishes faster than the exhaustive diagonal. All five finished well inside the gate’s two-minute budget. The axis is logarithmic so the millisecond runs stay visible next to the 3.68 s bar.

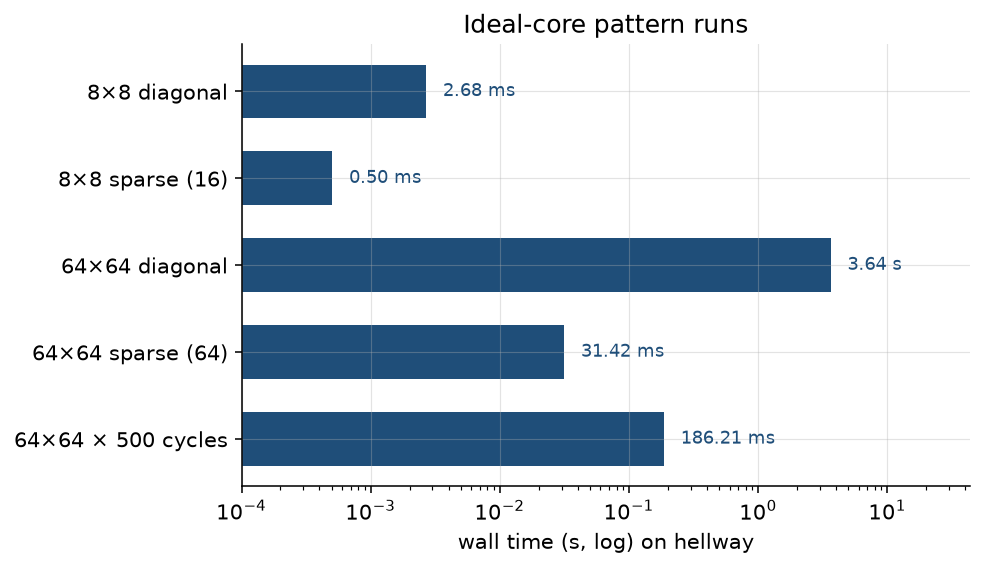
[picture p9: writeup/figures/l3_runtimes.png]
Wall-clock time of the ideal-core patterns on hellway, 4 October 2026.


## The fabric, then the boards

### Octal tiles

The 256 drive ends remain a physical fact of the plane. They are not the pin list of a sheet. A monolithic steer sheet would carry on the order of 320 pins, and the root would then instance those ends twice. L4 emits octal tiles instead: 34 pins each, one axis and one group of eight lines. The 64×64 fabric has sixteen of those tiles and 512 steering diodes. The 2×2 bring-up fabric has two tiles, X and Y at group 0, and 16 diodes. Both projects put four decode calls on the root. The fold stays local to the magnetic sheet: `YA66` and `YB65` join as `SENSE_FOLD`, and the fabric manifest records the sense nets as disjoint from the drive tiles.

KiCad 10.0.6 electrical rules on both projects, stamped 17:52 on 4 October 2026, returned empty error lists. The gate is **GATE-L4-FABRIC**. A topological fix goes back through the weave AST and the emitter; the sheets under `kicad/bringup_2x2/` and `kicad/driver_64x64/` are generated. Pin budgets live in [docs/hierarchy_abi.md](../docs/hierarchy_abi.md). Geometry lives in [`generators/mce_array.py`](../generators/mce_array.py).

### Two copper designs

The fabric is one drawing of the whole driver. The thing that can be repeated on a bench is two boards. One host, `ccs_sense`, holds the three current sources, the sense path, the fold, the write-back latch, and the bus that fans address and `VDRIVE` out. The axis board is the same copper for X and for Y. Straps pick the axis and the group address. Bring-up is one host and two axis boards, both at group 0, which is an 8×8. The full plane is that same host and sixteen axis boards, eight X and eight Y. The roster is written down. The coverage cell for a uniquely addressed 1+16 harness is still a stub. Packaging is [docs/board_icd.md](../docs/board_icd.md); quantities are [docs/component_selection.md](../docs/component_selection.md) §6.

What the 8×8 PCB cell actually cleared, on the same KiCad at 18:54 that day: empty ERC error lists, and DRC with no violations and no unconnected items, on both `pcb_ccs_sense` and `pcb_axis_octal`. The gate counts errors. ERC ignored a global label that appears once, four-way junctions, SPICE model issues, and footprint-filter mismatch. DRC ignored missing courtyards, footprint-filter and footprint-type mismatch, and two track-geometry checks that do not apply to a board with no tracks. Warnings were not promoted. Empty error lists are what the matrix calls pass.

The schematics carry the bill the selection note names. On the host: TL431, a 3296W trimpot, OPA192, and IRLZ44N, three times, plus BAT54S, TLV3501, and the 74AHC74 latch. On each axis board: two 74AHC138, two 74AHC238, TBD62783 and TBD62083 in forward and reverse, and 32 SS14s. Sense nets `YA65`, `YB66`, `YA66`, and `YB65` stay on the host. They do not appear on the axis sheet. Bring-up therefore totals 64 steering diodes and four of each DMOS array; the full roster totals 512 diodes and 32 of each array, which is the same diode count the 64×64 fabric already emits.

The copper on the board is the headers. Each net is given a single pad, so the check stays clean without an autorouter. The schematic Pico header still lists address, enables, and power. The PCB footprint keeps `SENSE_STROBE`, `DOUT`, and `PIO_STROBE`. The sense connector keeps the four fold ends; `AGND` returns on the bus. The BOM footprints are placed — three CCS strips and the sense parts on a 220×120 mm host, decode, DMOS, and a 32-diode grid on a 160×140 mm axis board — and the files contain no tracks. The stack in those files is two layers. The packaging contract still prefers four layers, and smaller outlines, at most 120×80 mm for the host and 100×80 mm for an axis board. Those size and stack targets belong to the board ICD. This layout has not met them. A clean DRC here means the placed connectors do not fight themselves.

## The edge of the record

The tree this essay describes has the contracts, the L0–L2 SPICE decks, the L3 ideal plant, the generated octal fabric, and two board projects whose 8×8 ERC/DRC cell is green. Firmware is not in the tree. The bench column is empty. The 64×64 PCB cell stays a stub until the sixteen uniquely strapped axis boards are a gated harness, not only a roster in [docs/board_icd.md](../docs/board_icd.md) §7.

Still open, and owned by the design-choices note rather than by this prose: the exact \(I_c\), the drive-rail voltage, inhibit polarity against the read, how the RP2040 is packaged, the CCS MOSFET alternate, and whether diagnostic LEDs are required. The 600 mA used in every figure above is the harness assumption, recorded so the plots can be read, and it is not a frozen setpoint.

The next emitter job is the copper between those footprints, a stack that matches the four-layer preference, and outlines inside the size targets. Bring-up, when it happens, starts at 2×2, on three boards.

To draw the figures again:

```bash
uv run --group writeup python writeup/scripts/render_figures.py
```

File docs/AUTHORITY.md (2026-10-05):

# Documentation authority (SSOT map)

**Status:** `baseline` (Phase 0 authority contract)

This file is the **SSOT map**, not the design itself. It names which document owns each fact category, how conflicts resolve, and how agents must navigate. Design content lives in the owner docs below.

Chat transcripts, agent scratchpads, and derived sketches are **not** authoritative.

## Status tags

Use these tags on claims and at the top of each doc:

| Tag | Meaning |
|-----|---|
| `baseline` | Approved Phase 0 contract; agents may synthesize / plan against it |
| `proposal` | Suggested change; outside baseline until explicitly promoted |
| `open` | Decision deferred (usually to bench); not frozen |
| `sketch` | Illustrative / non-authoritative; must not override owners |

## Conflict priority

When two sources disagree:

1. **This ownership table** (which doc is allowed to define the fact)
2. **Owning document** section for that category
3. **Derived docs** (README snapshot, implementation sketch, theory summary)
4. **Chat / prior agent turns**

If implementation or simulation contradicts an owner: **update the owner first**, then adapt consumers. Do not “fix forward” in a sketch or chat and leave the owner stale.

## Link, do not copy

Normative facts have **one editable home**. Downstream docs must **link** to the owner (file + section or stable ID). Do not restate fold geometry, BOM MPNs, naming regex, or gate criteria in full elsewhere—summaries of one sentence plus a link are fine.

## Ownership table (Layer B — contract owners)

| Information category | Authoritative owner | Must not own |
|---|---|---|
| Process, normative freeze table, L0–L4 gates, anti-explosion rules | [system_design_spec.md](system_design_spec.md) | Block wiring narrative |
| Plane physical ICD, sense/inhibit electrical contract, timing sequence | [design_specification.md](design_specification.md) | Process phases |
| Net grammar, naming layers, decode/DMOS call model | [naming.md](naming.md) | Pin-budget tables |
| Steer/magnetic pin budgets, octal tile ABI | [hierarchy_abi.md](hierarchy_abi.md) | Timing prose |
| BOM MPNs and part rationale | [component_selection.md](component_selection.md) | ICD geometry |
| Tradeoffs + open decisions | [design_choices.md](design_choices.md) | Frozen ICD |
| Multi-board packaging (1× CCS host + 2×8 axis-octal) | [board_icd.md](board_icd.md) | Electrical ABI / pin budgets |
| Scale × surface verification claims | [coverage_matrix.md](coverage_matrix.md) (+ future regression scripts) | Architecture invention |

## Derived / non-authoritative (Layer C)

| Doc | Role |
|-----|---|
| [implementation_summary.md](implementation_summary.md) | Target block **sketch** only |
| [theory_of_operation.md](theory_of_operation.md) | Teaching summary |
| [references.md](references.md) | Evidence / citation pointers |
| [dev_host_setup.md](dev_host_setup.md) | Ubuntu apt + `uv` host procedure |
| [../README.md](../README.md) | Human front door; architecture snapshot defers to owners |
| [../AGENTS.md](../AGENTS.md) | Agent entry; points here; does not define ICD |

## Machine golden source (Layer D)

Markdown contract owners remain baseline for ICD / BOM / timing. **Weave / fabric geometry** SSOT for generated KiCad is now:

1. **Weave / fabric geometry SSOT** → [`generators/mce_array.py`](../generators/mce_array.py) (+ [`generators/emit_kicad.py`](../generators/emit_kicad.py) emitter). Do not hand-edit `kicad/**` sheets; regenerate with `uv run python -m generators.cli --n 2|64`.
2. **Multi-board PCB SSOT** → [`generators/board_abi.py`](../generators/board_abi.py) + [`generators/emit_boards.py`](../generators/emit_boards.py) → `kicad/pcb_ccs_sense/`, `kicad/pcb_axis_octal/`; `uv run python -m generators.cli --board ccs|axis`. Packaging contract: [board_icd.md](board_icd.md).
3. Human ICD docs stay owner for electrical contracts; geometry emitted from the AST must conform to [hierarchy_abi.md](hierarchy_abi.md) / [naming.md](naming.md).
4. **Verification SSOT** → [coverage_matrix.md](coverage_matrix.md) rows + regression exit codes (simulator / `kicad-cli` ERC/DRC as oracle for that layer)

Formal YAML/TLA+ conversion of the full ICD remains out of scope; geometry SSOT for fabric is the AST above.

## Agent navigation

1. Read [../AGENTS.md](../AGENTS.md) (hard bans + entry).
2. Read **this file** (who owns the fact).
3. Open only the **owner** doc for the task; follow links for adjacent categories.
4. Before any scale claim, check [coverage_matrix.md](coverage_matrix.md).

## Stable IDs

Owner docs use anchors such as `REQ-ICD-FOLD`, `REQ-DRV-DMOS`, `GATE-L1-CYCLE` for future REQ → sim → bench tracing. Prefer citing those IDs over paraphrasing.

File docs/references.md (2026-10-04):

# References

**Status:** `sketch` (evidence pointers; placeholders)  
Citation keys used by [design_specification.md](design_specification.md). Full bibliography and scanned evidence are deferred; placeholders below keep normative links resolvable. Authority: [AUTHORITY.md](AUTHORITY.md).

## Core plane physical evidence

| Key | Claim | Status |
|-----|---|---|
| `[cite: 1]` | 9″ plane, XA/XB/YA/YB edge connectors, pin geometry and top-face odd pins | Placeholder — attach photos/measurements in a later pass |
| `[cite: 2]` | Bottom-face even pins; sense pins 65/66; no diodes on plane | Placeholder — attach photos/measurements in a later pass |

Until evidence files land, treat connector dimensions and pin maps in [design_specification.md](design_specification.md) §1 as the working ICD from the prior project’s characterization, subject to re-verification on the physical plane.

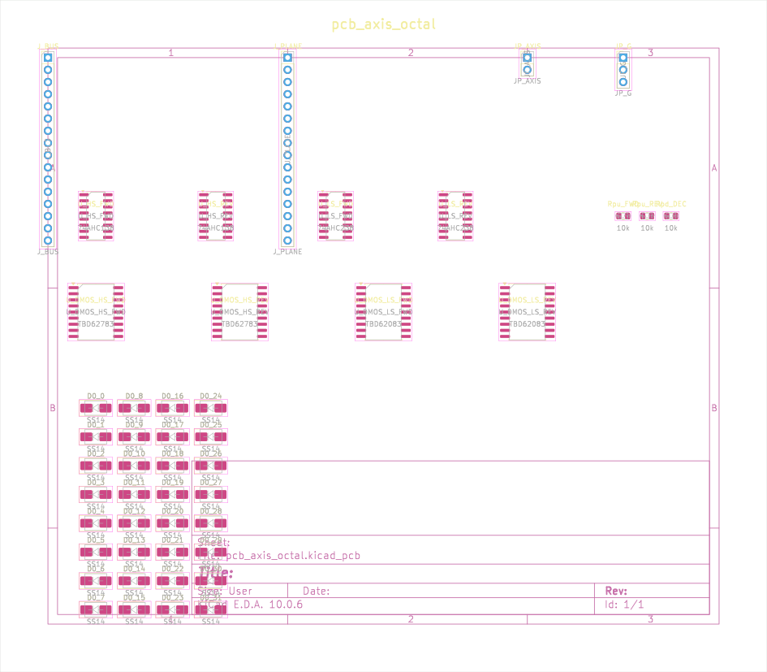
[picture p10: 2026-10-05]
kicad/_preview/pcb_axis_octal-pcb.png

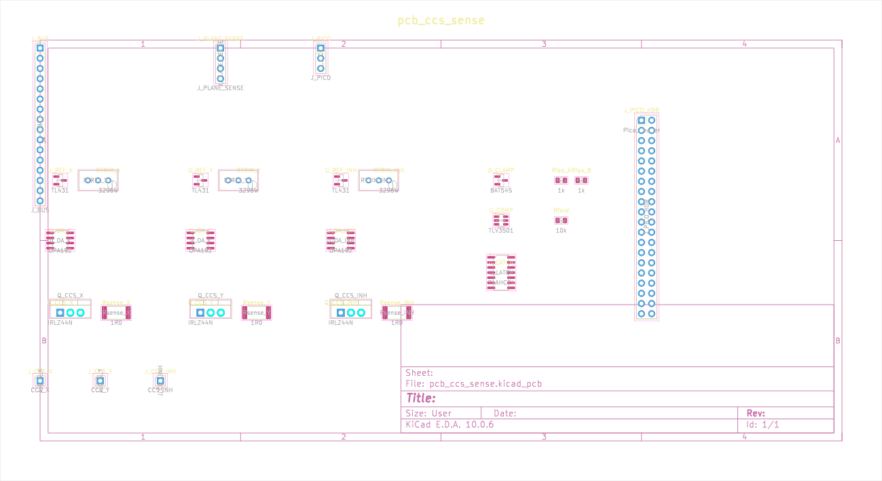
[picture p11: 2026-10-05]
kicad/_preview/pcb_ccs_sense-pcb.png

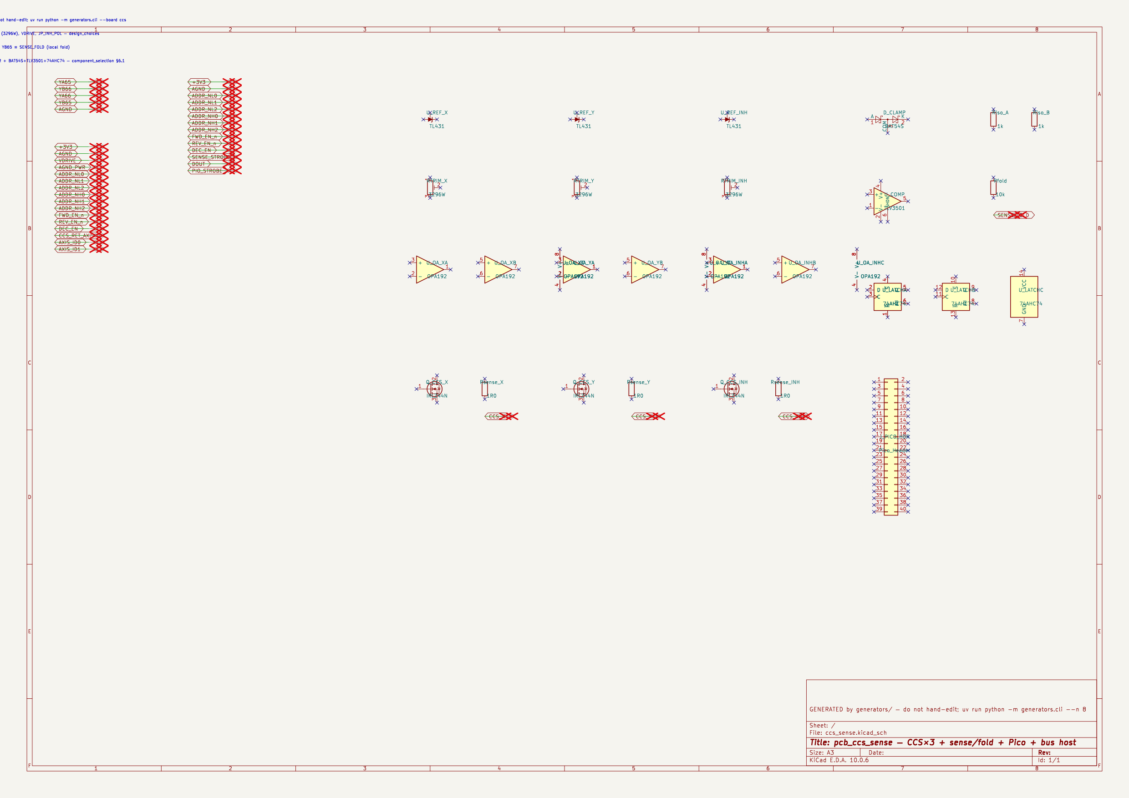
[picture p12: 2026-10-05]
kicad/_preview/pcb_ccs_sense-sch.png

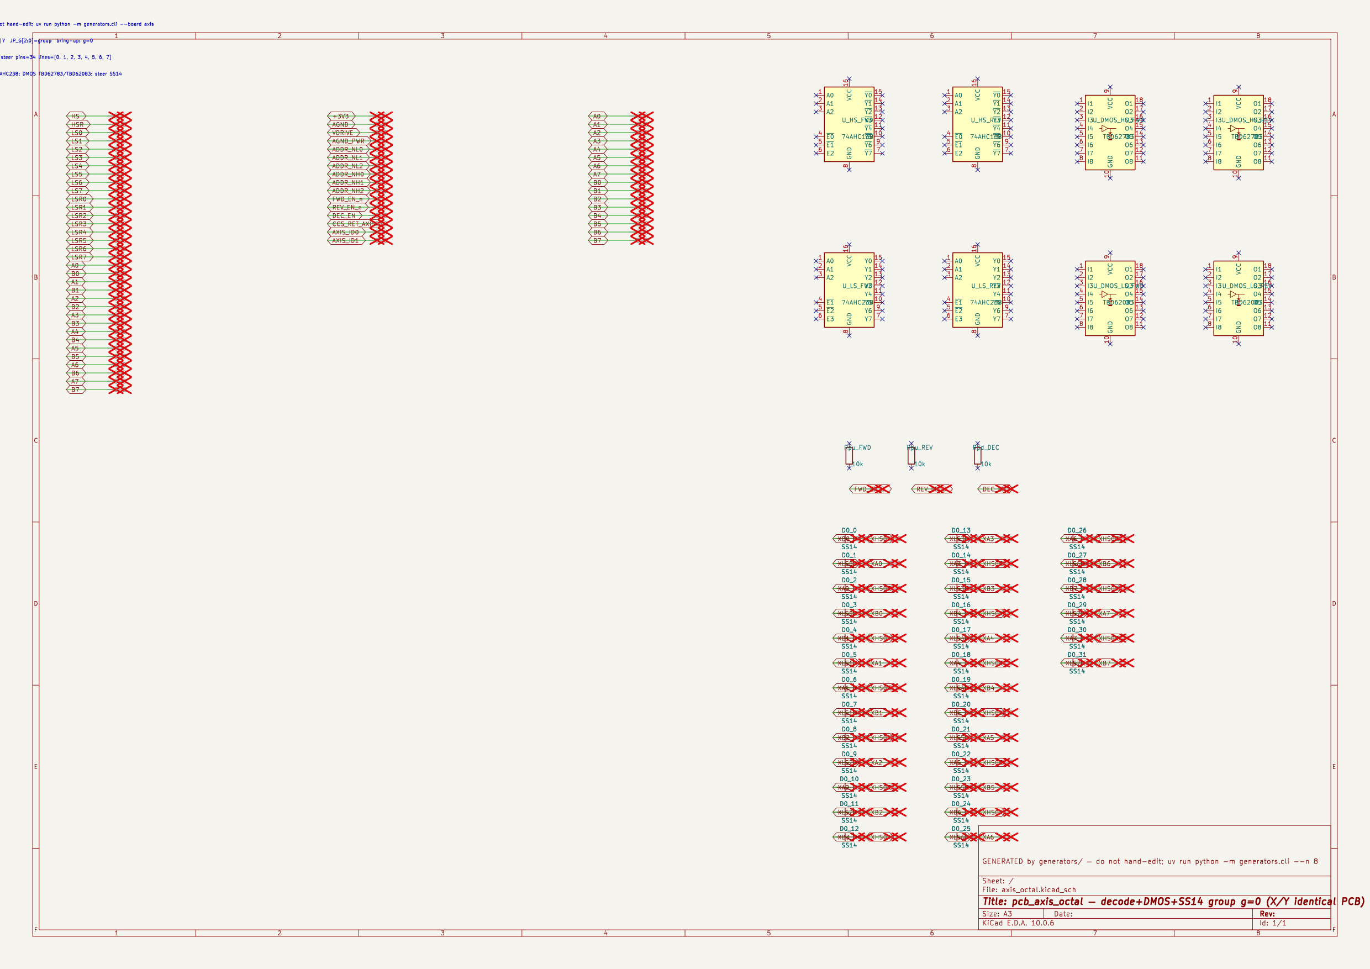
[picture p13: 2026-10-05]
kicad/_preview/pcb_axis_octal-sch.png

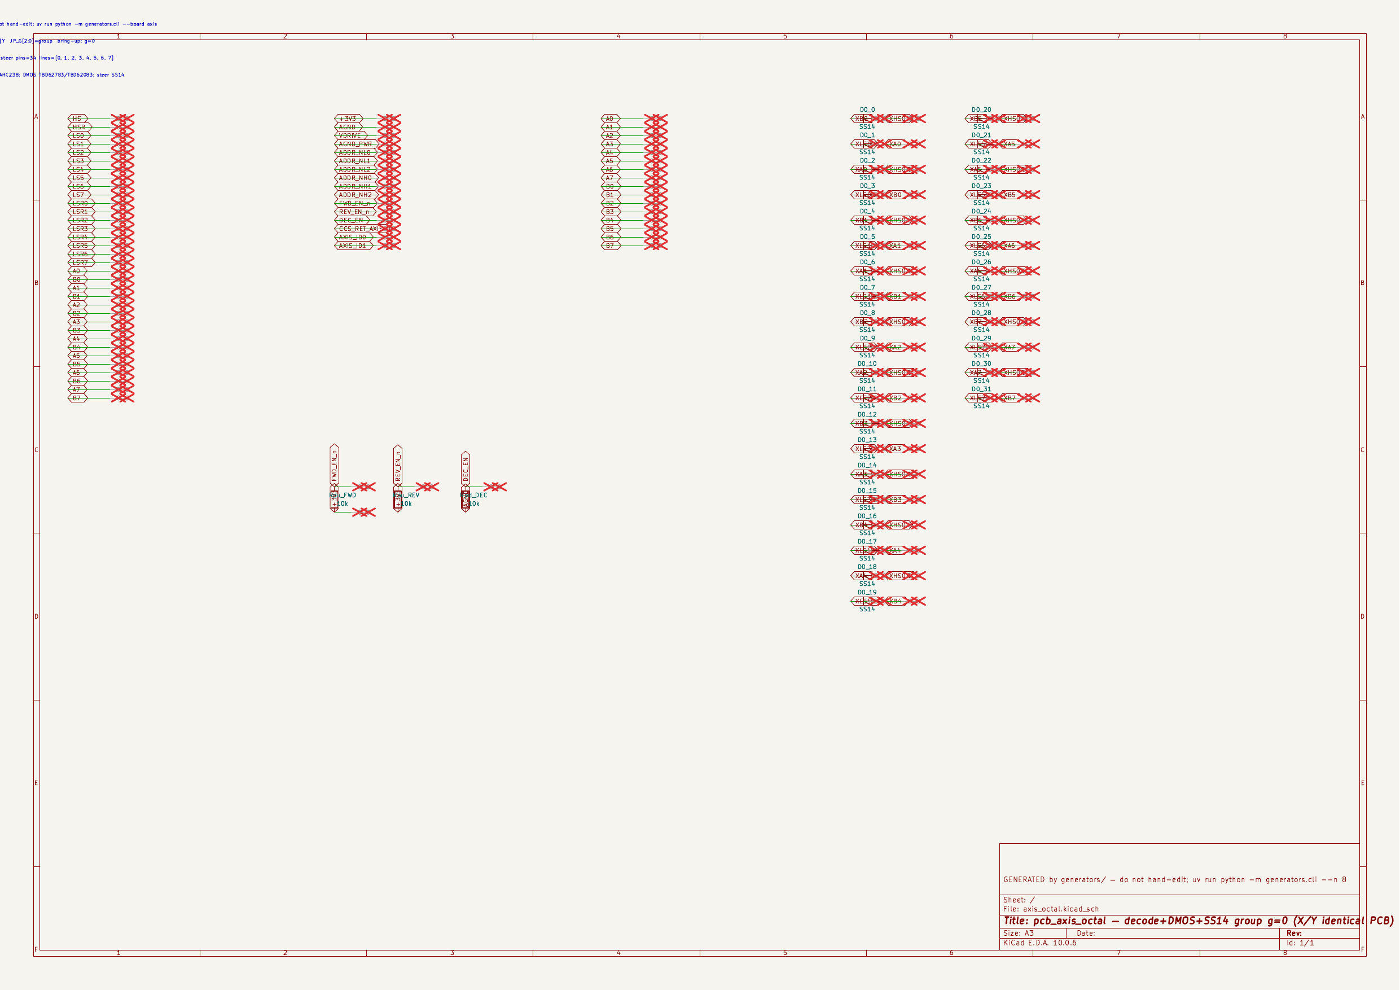
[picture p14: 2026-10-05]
kicad/_preview/pcb_axis_octal-1.png

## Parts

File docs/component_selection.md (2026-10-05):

# Component Selection

**Status:** `baseline` (Phase 0 contract)  
**Owns:** BOM MPNs and part rationale  
**Does not own:** ICD geometry — see [AUTHORITY.md](AUTHORITY.md)

Architecture rationale: [design_choices.md](design_choices.md). Process / anti-explosion: [system_design_spec.md](system_design_spec.md). Target block sketch (non-authoritative): [implementation_summary.md](implementation_summary.md).

Offline datasheet PDFs and appnotes are **deferred** (no `datasheets/` tree in this repo yet). MPN names below are the normative BOM picks.

---

## 1. Address Decoding & Matrix Gate Drive (DMOS pivot)

**REQ-DRV-DMOS** — L2 / normative drive path is AHC decode → TBD62783 / TBD62083 (not TC4427A + FDS8958A).

To avoid a discrete MOSFET + gate-driver forest, the design uses modern DMOS sink/source arrays. These give SN75325-like density with FET switching speed (avoiding Darlington/BJT turn-off drag that would blur the inductive read spike).

| MPN | Role | Package | Key params | Alternate | Datasheet |
|-----|---|---|---|---|---|
| 74AHC138 | 3-to-8 decoder HS (×4: FWD/REV × X-H/Y-H) | SOIC-16 | Active-low Y0–Y7; bank enables | 74HC138 | deferred |
| 74AHC238 | 3-to-8 decoder LS (×4: FWD/REV × X-L/Y-L) | SOIC-16 | Active-high Y0–Y7; same enables as 138 | 74HC238 | deferred |
| TBD62783 | 8-channel DMOS source array (HS) | SOIC-18 | 500 mA/ch; replaces P-FETs + TC4427 | — | deferred |
| TBD62083 | 8-channel DMOS sink array (LS) | SOIC-18 | 500 mA/ch; replaces N-FETs + TC4427 | — | deferred |

**Architecture impact:** TBD62x83 inputs accept 3.3 V AHC decoder outputs directly. 74AHC138 (active-low) drives TBD62783 sources; 74AHC238 (active-high) drives TBD62083 sinks. This discards the old discrete MOSFET staged bring-up as the primary architecture.

**KiCad symbol vs MPN:** pin-compatible lib_id `74xx:74HC138` / `74xx:74HC238` with Value set to the ordered MPN (`74AHC138` / `74AHC238`). Do not treat the HC lib_id as the BOM part.

---

## 2. The Steer Matrix (64×64)

| MPN | Role | Package | Key params | Alternate | Datasheet |
|-----|---|---|---|---|---|
| SS14 | Steering Schottky | SMA | 1 A, low Vf, fast recovery | SS16 (higher Vr) | deferred |

The 8×8 addressing geometry creates sneak paths across unselected lines. SS14 diodes remain mandatory on the driver at matrix outputs. The plane itself contains no diodes. Long-term fabric: octal steer tiles ([hierarchy_abi.md](hierarchy_abi.md)).

---

## 3. Constant-Current Sink (manual)

Low-side matrix returns share an adjustable CCS so \(I_c/2\) stays flat into the inductive load (target band ~200–400 mA).

| MPN | Role | Package | Key params | Alternate | Datasheet |
|-----|---|---|---|---|---|
| TL431 | Precision shunt reference | SOT-23 / TO-92 | Stable Vref for setpoint divider | TLV431 (lower Vref) | deferred |
| Bourns 3296W | 10 kΩ multi-turn trimpot | 3296W | Bench adjustment of \(I_c/2\) | 3296Y (side adjust) | deferred |
| OPA192 | Feedback error amp | SOIC-8 | 10 MHz GBW, fast slew | OPA191 | deferred |
| IRLZ44N | Throttle N-MOSFET (CCS) | TO-220 / DPAK family | Linear-region dissipation | AOD4184 | deferred |
| 1.0 Ω 1% 2 W | Current sense | 2512 SMD | Low inductance thick film | 0.47 Ω (if higher I) | — |

Speed matters when the drive pulse hits: the op-amp must contain inductive overshoot within the microsecond pulse. The throttle MOSFET runs in its linear region and must handle the waste heat.

---

## 4. Sense & Inhibit Front End (pins 65 & 66)

Isolates the differential read pulse from common-mode noise and protects the amp during inhibit.

| MPN | Role | Package | Key params | Alternate | Datasheet |
|-----|---|---|---|---|---|
| BAT54S | Dual series Schottky clamp | SOT-23 | Clamp YA65/YB66 to rails | BAT54C | deferred |
| TLV3501 | High-speed comparator (Sense) | SOT-23-5 / SOIC | 4.5 ns tpd, 3.3 V logic out | LT1016 (legacy ±5 V class) | deferred |
| 74AHC74 | D flip-flop read latch | SOIC-14 | Captures comparator on SENSE STROBE | 74LVC74 | deferred |

Sense uses **TLV3501** (not LT1016): single-supply 3.3 V logic-friendly output and short propagation delay. Classic comparator layout/strobe advice (Linear AN13) remains useful; PDF deferred. Latch clocks ~150–300 ns into READ to miss capacitive ringing and catch the core flip.

---

## 5. Hardware Testability

| MPN / series | Role | Package | Key params | Alternate | Datasheet |
|---|---|---|---|---|---|
| Keystone 5000-series | Loop test points | Through-hole loop | SENSE STROBE, DOUT, Isense | Equivalent loop TP | deferred |
| 2N7002 | LED buffer N-MOSFET | SOT-23 | Decoder / DOUT indicators | 2N7002K | deferred |
| 0805 LED | Diagnostic indicators | 0805 | Address + data visibility | — | — |

Populate loop-style test points on SENSE STROBE, the sense-latch output, and the current-sense node. Decoder/DOUT LEDs are planned but not a frozen schematic requirement ([design_choices.md](design_choices.md) open decisions).

---

## 6. Multi-board PCB BOM (quantities)

Packaging split: [board_icd.md](board_icd.md). MPNs above remain normative; this section owns **how many** of each part go on `ccs_sense` vs `axis_octal`, and roll-ups for bring-up vs full array.

Machine-readable roll-up: [`bom_multiboard.csv`](bom_multiboard.csv).

### 6.1 Per `ccs_sense` board (qty 1 forever)

| MPN / value | Role | Pkg | Qty / board |
|---|---|-----|---:|
| TL431 | CCS Vref (×3 channels) | SOT-23 | 3 |
| Bourns 3296W 10 kΩ | CCS trim (`RTRIM_X/Y/INH`) | 3296W | 3 |
| OPA192 | CCS error amp | SOIC-8 | 3 |
| IRLZ44N | CCS throttle MOSFET | TO-220 / DPAK | 3 |
| 1.0 Ω 1% 2 W | CCS sense | 2512 | 3 |
| BAT54S | Sense clamp | SOT-23 | 1 |
| TLV3501 | Sense comparator | SOT-23-5 | 1 |
| 74AHC74 | Write-back latch → `DOUT` | SOIC-14 | 1 |
| 1 kΩ | Sense isolation | 0805 | 2 |
| 10 kΩ | `SENSE_FOLD` soft bias | 0805 | 1 |
| PinHeader 1×16 | `J_BUS` host | 2.54 mm | 1 |
| PinHeader 1×4 | `J_PLANE_SENSE` | 2.54 mm | 1 |
| PinHeader 1×3 | `J_PICO` timing/`DOUT` (PCB) | 2.54 mm | 1 |
| PinHeader 1×1 | `J_CCS_X/Y/INH` | 2.54 mm | 3 |
| Raspberry Pi Pico H (or header) | PIO timing — packaging open | — | 1 |
| Keystone 5000-series | TP: STROBE / DOUT / Isense | loop | 3 |

Supporting divider/bypass passives around TL431/OPA192 are implied by the CCS topology and will appear as schematic detail densifies; do not invent extra MPNs here.

### 6.2 Per `axis_octal` board (identical X/Y; strap `JP_AXIS` / `JP_G`)

One board = one HS group (`g`), FWD+REV, 8 lines → **32× SS14** (4 diodes/line).

| MPN / value | Role | Pkg | Qty / board | Notes |
|---|---|-----|---:|---|
| 74AHC138 | HS decode FWD + REV | SOIC-16 | 2 | Board enables when `ADDR_NH` matches `JP_G` |
| 74AHC238 | LS decode FWD + REV | SOIC-16 | 2 | 8 LS sinks per direction |
| TBD62783 | HS DMOS FWD + REV | SOIC-18 | 2 | 1 of 8 channels used for this group’s `HS`/`HSR` |
| TBD62083 | LS DMOS FWD + REV | SOIC-18 | 2 | All 8 channels used |
| SS14 | Steer Schottky | SMA | **32** | Diode law per [hierarchy_abi.md](hierarchy_abi.md) |
| 10 kΩ | `FWD_EN_n` / `REV_EN_n` pull-up; `DEC_EN` pull-down | 0805 | 3 | Fail-safe |
| PinHeader 1×16 | `J_BUS` | 2.54 mm | 1 | |
| PinHeader 1×16 | `J_PLANE` A/B[0..7] | 2.54 mm | 1 | |
| PinHeader 1×2 | `JP_AXIS` | 2.54 mm | 1 | |
| PinHeader 1×3 | `JP_G` | 2.54 mm | 1 | |

### 6.3 System roll-up

| Build | `ccs_sense` | `axis_octal` | SS14 total | TBD62783 | TBD62083 | 74AHC138 | 74AHC238 |
|---|---:|---:|---:|---:|---:|---:|---:|
| **Bring-up 8×8** | 1 | 2 | 64 | 4 | 4 | 4 | 4 |
| **Full 64×64** | 1 | 16 | 512 | 32 | 32 | 32 | 32 |

Matches [`bom_multiboard.csv`](bom_multiboard.csv) columns `Bringup_1ccs_2axis` / `Full_1ccs_16axis` and the board roster in [board_icd.md](board_icd.md) §7.1 (**1 + 2×8**). CCS/sense ICs stay at the **per-host** counts in §6.1 for both builds (one host). Diagnostic LEDs / 2N7002 remain optional ([design_choices.md](design_choices.md)).

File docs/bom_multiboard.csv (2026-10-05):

MPN | Role | Package | Board | Qty_per_board | Bringup_1ccs_2axis | Full_1ccs_16axis | Notes
TL431 | CCS Vref | SOT-23 | ccs_sense | 3 | 3 | 3 | One per CCS_X/Y/INH
3296W-10k | CCS trimpot | 3296W | ccs_sense | 3 | 3 | 3 | RTRIM_X/Y/INH
OPA192 | CCS error amp | SOIC-8 | ccs_sense | 3 | 3 | 3
IRLZ44N | CCS throttle MOSFET | TO-220/DPAK | ccs_sense | 3 | 3 | 3 | Alternate AOD4184
1R0-1pct-2W | CCS sense resistor | 2512 | ccs_sense | 3 | 3 | 3
BAT54S | Sense clamp | SOT-23 | ccs_sense | 1 | 1 | 1
TLV3501 | Sense comparator | SOT-23-5 | ccs_sense | 1 | 1 | 1
74AHC74 | Write-back latch | SOIC-14 | ccs_sense | 1 | 1 | 1 | DOUT
R-1k | Sense isolation | 0805 | ccs_sense | 2 | 2 | 2
R-10k | SENSE_FOLD bias | 0805 | ccs_sense | 1 | 1 | 1
PinHeader-1x16 | J_BUS host | 2.54mm TH | ccs_sense | 1 | 1 | 1
PinHeader-1x04 | J_PLANE_SENSE | 2.54mm TH | ccs_sense | 1 | 1 | 1
PinHeader-1x03 | J_PICO timing | 2.54mm TH | ccs_sense | 1 | 1 | 1 | PCB subset; ADDR on J_BUS
PinHeader-1x01 | J_CCS_X/Y/INH | 2.54mm TH | ccs_sense | 3 | 3 | 3
Raspberry-Pi-Pico-H | PIO timing |  | ccs_sense | 1 | 1 | 1 | Packaging open
Keystone-5000 | Test points | loop TH | ccs_sense | 3 | 3 | 3 | STROBE/DOUT/Isense
74AHC138 | HS decode FWD+REV | SOIC-16 | axis_octal | 2 | 4 | 32 | Per axis board
74AHC238 | LS decode FWD+REV | SOIC-16 | axis_octal | 2 | 4 | 32 | Per axis board
TBD62783 | HS DMOS FWD+REV | SOIC-18 | axis_octal | 2 | 4 | 32 | 1/8 channels used per group
TBD62083 | LS DMOS FWD+REV | SOIC-18 | axis_octal | 2 | 4 | 32 | 8/8 channels used
SS14 | Steer Schottky | SMA | axis_octal | 32 | 64 | 512 | 4 diodes x 8 lines
R-10k | Fail-safe EN pulls | 0805 | axis_octal | 3 | 6 | 48 | FWD/REV pull-up + DEC pull-down
PinHeader-1x16 | J_BUS | 2.54mm TH | axis_octal | 1 | 2 | 16
PinHeader-1x16 | J_PLANE | 2.54mm TH | axis_octal | 1 | 2 | 16 | A/B 0..7
PinHeader-1x02 | JP_AXIS | 2.54mm TH | axis_octal | 1 | 2 | 16
PinHeader-1x03 | JP_G | 2.54mm TH | axis_octal | 1 | 2 | 16 | g=0..7 strap

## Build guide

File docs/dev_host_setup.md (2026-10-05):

# Dev-host setup (Ubuntu)

**Status:** `sketch` (derived host procedure — does not override design owners)  
**Owns:** Ubuntu apt + `uv` install steps for the planned SIL/generator host  
**Does not own:** ICD, BOM, timing, or fabric ABI — see [AUTHORITY.md](AUTHORITY.md)

The steps below install the **host baseline** for L0–L3 sim/SIL and L4 schematic fabric (`kicad-cli` ERC). Design contracts stay under [`docs/`](./); do not invent ad-hoc environments.

**Target OS:** Ubuntu 22.04 / 24.04 (package names below match both unless noted).

## 1. System packages (required for SIL host)

```bash
sudo apt update
sudo apt install -y \
  build-essential curl git ca-certificates \
  ngspice libngspice0-dev
```

| Package | Role |
|---|---|
| `build-essential` | Compilers / make for native Python wheels when needed |
| `curl` / `git` / `ca-certificates` | Fetch uv, clone, TLS |
| `ngspice` | CLI SPICE engine |
| `libngspice0-dev` | Shared library plus unversioned `libngspice.so` symlink that PySpice expects |

## 2. Install uv

Prefer the [official standalone installer](https://docs.astral.sh/uv/getting-started/installation/) over distro `pip`:

```bash
curl -LsSf https://astral.sh/uv/install.sh | sh
```

Ensure `~/.local/bin` is on your `PATH` (open a new shell or source your profile), then:

```bash
uv --version
```

## 3. Project Python environment

From the repository root:

```bash
uv python install 3.12
uv sync
uv run python -c "import PySpice; print(PySpice.__version__)"
```

NgSpice / PySpice smoke check (use this, not upstream `--check-install`):

```bash
uv run python scripts/check_pyspice.py
```

**Note (Ubuntu 24.04 / ngspice 42 + PySpice 1.5):** Upstream
`uv run pyspice-post-installation --check-install` fails with
`NgSpiceCommandError: Command 'run' failed` even when the transient
succeeds. Newer ngspice prints `Using SPARSE 1.3 as Direct Linear Solver`
on stderr; PySpice 1.5 treats any non-`Warning:` stderr as fatal
([PySpice#379](https://github.com/PySpice-org/PySpice/issues/379)).
`scripts/check_pyspice.py` ignores that informational line and verifies a
real transient.

`uv sync` creates `.venv` from [`pyproject.toml`](../pyproject.toml) and the committed `uv.lock`. L0–L3 modules live under `spice/`; L4 fabric generators under `generators/` emit into `kicad/`.

## 4. KiCad 10.0.6 (required for GATE-L4-FABRIC)

KiCad is **not** required for L0–L3 PySpice gates. It **is** required to emit/check L4 hierarchical schematics (`kicad-cli sch erc`).

**Pinned host version:** **10.0.6** (current stable). Use the official [KiCad 10.0 releases PPA](https://launchpad.net/~kicad/+archive/ubuntu/kicad-10.0-releases) — do **not** rely on the Ubuntu universe package (often years behind on 22.04/24.04). Upstream install notes: [kicad.org/download/ubuntu](https://www.kicad.org/download/details/ubuntu/).

### Install (official 10.0 PPA)

```bash
sudo add-apt-repository --yes ppa:kicad/kicad-10.0-releases
sudo apt update
sudo apt install --install-recommends -y kicad
```

That installs the GUI (`kicad`), CLI (`kicad-cli`), and recommended libraries. Confirm the package version lands on 10.0.6:

```bash
apt-cache policy kicad | head -20
# Candidate should look like: 10.0.6~ubuntu24.04.1 (or ~ubuntu22.04.1)
```

If an older distro `kicad` was already installed, the PPA upgrade should replace it after `apt update` + install. Prefer removing leftover nightly/testing PPAs (`kicad-10.0-nightly`, etc.) so apt does not prefer a non-stable build.

### Verify CLI

```bash
kicad-cli --version
kicad-cli sch --help
```

Expect a **10.0.6** version string and a `sch` subcommand that lists `erc`.

### ERC smoke (after generators have produced a project)

```bash
# From repo root, after: uv run python -m generators.cli --n 2
kicad-cli sch erc --format report --output /tmp/bringup_erc.rpt \
  kicad/bringup_2x2/driver.kicad_sch
```

Or run the gate wrapper (preferred):

```bash
uv run python scripts/run_gate.py GATE-L4-FABRIC
# or: uv run python scripts/run_kicad_erc.py
```

### NgSpice / PySpice coexistence

KiCad may pull in `libngspice-kicad`, which can collide with `libngspice0` / `libngspice0-dev`. If PySpice then fails to find `libngspice.so`, create a symlink to the versioned library (paths may vary by arch):

```bash
# amd64 example — adjust libdir for arm64 if needed
sudo ln -sf /usr/lib/x86_64-linux-gnu/libngspice.so.0 \
  /usr/lib/x86_64-linux-gnu/libngspice.so
```

Re-run `uv run python scripts/check_pyspice.py` after installing KiCad.

### GUI (optional)

```bash
kicad   # or open kicad/bringup_2x2/*.kicad_pro from the file manager
```

Help → About is fine for a human sanity check; gates use `kicad-cli` only.

## 5. Explicitly not installed

- **RP2040 / Pico SDK** — deferred; not part of the current host setup. Timing design still assumes programmable I/O in the ICD; firmware tooling waits until bring-up.

## 6. Verify checklist

- [ ] `uv --version`
- [ ] `ngspice -v`
- [ ] `uv run python -c "import PySpice; print(PySpice.__version__)"`
- [ ] `uv run python scripts/check_pyspice.py`
- [ ] `uv run python scripts/run_gate.py GATE-L0-PHYSICS` (or `uv run pytest tests/test_l0_physics.py`)
- [ ] `uv run python scripts/run_gate.py GATE-L1-CYCLE` (or `uv run pytest tests/test_l1_cycle.py`)
- [ ] `uv run python scripts/run_gate.py GATE-L2-E2E` (or `uv run pytest tests/test_l2_e2e.py`)
- [ ] `uv run python scripts/run_gate.py GATE-L3-SIL` (or `uv run pytest tests/test_l3_sil.py`)
- [ ] `kicad-cli --version` shows **10.0.6** (required for L4; from `ppa:kicad/kicad-10.0-releases`)
- [ ] `uv run python scripts/run_gate.py GATE-L4-FABRIC` (or `uv run pytest tests/test_l4_fabric.py`)

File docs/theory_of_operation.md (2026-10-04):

# Theory of Operation (summary)

**Status:** `sketch` (teaching summary; non-authoritative)  
Plane/timing contract: [design_specification.md](design_specification.md). Authority: [AUTHORITY.md](AUTHORITY.md). Cite keys: [references.md](references.md).

## Coincident-current half-select

Each core sits at an X/Y crossing. A full write or destructive read needs roughly \(I_c\) through the selected core. The driver puts \(I_c/2\) on one X line and \(I_c/2\) on one Y line so only the intersection sees full-select; half-selected cores on those lines must not flip.

Forward polarity (READ) and reverse polarity (WRITE/RESTORE) are steered by separate decoder/DMOS banks (`FWD_EN_n` / `REV_EN_n`).

## Three-wire sense and series inhibit

This plane has no fourth inhibit winding. The sense wire is time-multiplexed:

* **READ:** millivolt differential pickup across the folded loop ends `YA65` / `YB66`.
* **INHIBIT (write-0 / restore-0):** \(I_c/2\) forced in series through both sense loops via the external fold `YA66`═`YB65`, opposing a WRITE-1 at the selected core.

Soft mid-tap bias and clamps protect the comparator during inhibit excursions.

## Destructive READ / RESTORE

A READ to zero destroys a stored one. Every access is therefore READ → (optional INHIBIT) → WRITE restore of the latched bit (or the new data). Timing must hold a stable strobe window (~150–300 ns into READ) before inhibit/write edges.

## Why scale is layered

Nonlinear ferrite models do not run at 4,096 cores inside a useful agent loop. Physics calibrates at L0; topology proves at 2×2; full-matrix coincidence uses behavioral cores at L3; CAD fabric tiles the 256 plane ends at L4. See [system_design_spec.md](system_design_spec.md).

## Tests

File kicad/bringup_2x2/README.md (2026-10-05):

# bringup_2x2 (GENERATED)

GENERATED by generators/ — do not hand-edit; uv run python -m generators.cli --n 2

- Root: `driver.kicad_sch`
- Manifest: `fabric_manifest.json`
- Gate: **GATE-L4-FABRIC** / **REQ-HIER-OCTAL**

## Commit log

2026-10-05 Add L4 KiCad fabric and multi-board CCS/axis PCB projects.
    Emit hierarchical fabric sheets and pcb_ccs_sense / pcb_axis_octal from generators; document 1-host + 2×8 axis packaging; gate ERC/DRC and sim tests green.
    [axis_octal.kicad_sch, ccs_channel.kicad_sch, ccs_sense.kicad_sch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]
2026-10-05 3 pcb breakout
2026-10-05 logical seperation into host and multiple decode/drive/steering boards
    [axis_octal.kicad_sch, bom_multiboard.csv, ccs_channel.kicad_sch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]
